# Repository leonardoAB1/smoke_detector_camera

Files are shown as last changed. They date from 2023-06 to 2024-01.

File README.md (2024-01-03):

# Smoke Detector Camera

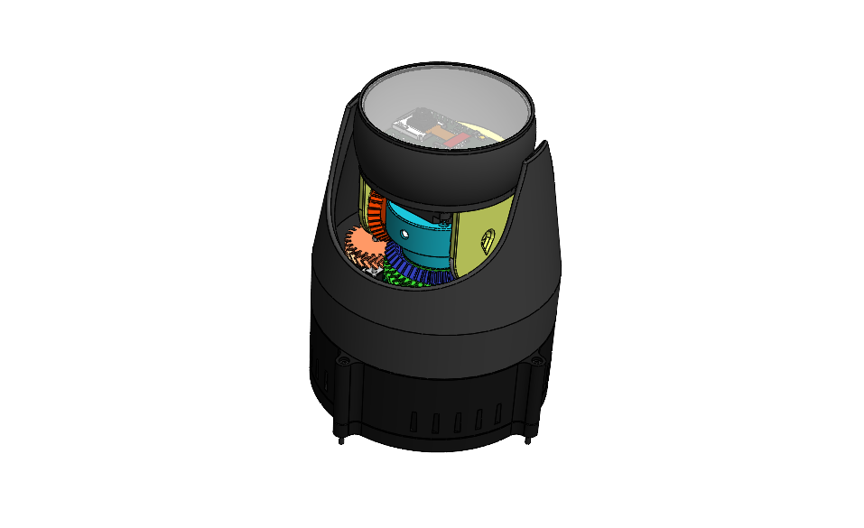
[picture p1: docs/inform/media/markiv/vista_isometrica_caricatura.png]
Vista Isometrica de la Version MK IV


"Smoke Detector Camera" is a project that aims to detect smokers and vaporizer users in a closed environment. The project combines the development of a local website using Django and web technologies such as HTML, CSS, and JavaScript, with the connection of an ESP32-CAM camera running FreeRTOS. Additionally, libraries like OpenCV and PyTorch will be used for image calculations and analysis.

The Django-based website will receive and display the data captured by the camera, as well as perform additional processing to successfully differentiate smokers from vaporizer users. Deep learning models and algorithms will be employed to detect and classify actions and gestures related to tobacco and vaporizer consumption.

Furthermore, there is a possibility of building a database to store captured images for long-term recording and analysis. The SQL database management system provided by Django will be utilized for this purpose.

In summary, "Smoke Detector Camera" is a project that combines web technologies, computer vision, and deep learning to detect and differentiate smokers from vaporizer users in a closed environment.

# IoT Project Directory Structure

This repository contains the directory structure for an IoT project. The structure is designed to organize the different components of the project and provide a logical arrangement for source code, documentation, configuration files, and more.

## Directory Structure

The project directory is structured as follows:

- **/docs**: Contains project documentation files, including system architecture, API documentation, and user manuals. The documentation is written in LaTeX.

- **/src**: Holds the source code files for different components of the IoT system.
  - **/device**: Contains device-specific code, firmware, or software that runs on the IoT devices/sensors.
  - **/gateway**: Includes code related to the gateway or edge computing component of the IoT project.
  - **/cloud**: Contains code related to the cloud or backend infrastructure, including data processing, storage, and API endpoints.

- **/config**: Contains configuration files for different components or modules within the project.

- **/tests**: Includes test files for unit tests, integration tests, or any other test-related files.

- **/data**: Contains data files required for the project, such as sample datasets.

- **/deploy**: Holds deployment-related files, such as deployment scripts or configuration files.

- **/scripts**: Contains utility scripts that assist in development, automation, or deployment tasks.

- **/logs**: Holds log files generated by the application or system.

- **/cad**: Contains CAD files related to the project, such as component designs, enclosures, schematics, and diagrams.

- **/electronics**: Holds electronics-related files, such as circuit diagrams, PCB layouts, datasheets, and schematics.

## Usage

To use this directory structure for your own IoT project, you can follow these steps:

1. Clone or download this repository to your local machine.

2. Customize the directories and subdirectories based on your project requirements.

3. Add your project-specific files and code to the corresponding directories.

4. Update the README.md file to provide an overview of your project and instructions for setup or usage.

## Contributing

If you have any suggestions or improvements for the directory structure or would like to contribute to this project, please feel free to submit a pull request.

## License

This project is licensed under the [MIT License](LICENSE).

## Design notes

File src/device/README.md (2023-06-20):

# Smoke Detector Camera - Servidor Móvil

## Descripción del proyecto

El proyecto Smoke Detector Camera utiliza la cámara ESP32-CAM para capturar video continuamente y enviarlo a un servidor para su procesamiento. El objetivo principal es detectar fumadores en las imágenes del video y tomar medidas en consecuencia.

El servidor móvil actúa como una interfaz de comunicación entre la cámara y el backend basado en Django. Recibe el video transmitido por la cámara y lo envía al servidor para su procesamiento. El servidor utiliza algoritmos de detección de fumadores para analizar las imágenes del video y generar resultados.

Este proyecto se basa en la plataforma ESP-IDF para el desarrollo del firmware de la cámara ESP32-CAM y en Django para el desarrollo del servidor.

## Características

- Captura y transmisión de video en tiempo real desde la cámara ESP32-CAM al servidor.
- Procesamiento de imágenes del video para detectar fumadores.
- Interfaz de comunicación entre la cámara y el servidor.
- Configuración sencilla y flexible a través de archivos de configuración.

## Requisitos previos

Antes de ejecutar el servidor móvil, asegúrate de tener los siguientes requisitos previos:

1. Cámara ESP32-CAM con firmware actualizado.
2. Servidor basado en Django correctamente configurado y en funcionamiento.
3. Conexión estable a internet.

# Web Server API Documentation

This document provides the documentation for the REST API of the web server implemented in the `web_server.c` file. The web server runs on an ESP32-CAM development board and provides various functionalities accessible through different URI endpoints.

## Base URL

The base URL for accessing the web server API is `http://localhost/` or `http://<ip_address>/` where `<ip_address>` is the IP address of the ESP32-CAM board.

## API Endpoints

The following table lists the available API endpoints along with their corresponding URIs, HTTP methods, and handlers:

| URI | Method | Handler | Description |
|---|---|---|---|
| `/image` | GET | `image_httpd_handler` | Get a single image |
| `/image64` | GET | `image_base64_httpd_handler` | Get a single image base64 encoded |
| `/status` | GET | `status_httpd_handler` | Get the camera status |
| `/admin` | POST | `admin_httpd_handler` | Admin functionality |
| `/motor_01/set` | POST | `handle_set_motor_angle` | Set the angle of motor 01 |
| `/motor_01/get` | GET | `handle_get_motor_angle` | Get the angle of motor 01 |
| `/motor_02/set` | POST | `handle_set_motor_angle` | Set the angle of motor 02 |
| `/motor_02/get` | GET | `handle_get_motor_angle` | Get the angle of motor 02 |
| `/ldr/set` | POST | `handle_set_ldr` | Set the state of the LDR |
| `/ldr/get` | GET | `handle_get_ldr` | Get the state of the LDR |
| `/led/set` | POST | `handle_set_led` | Set the state of the LED |
| `/led/get` | GET | `handle_get_led` | Get the state of the LED |
| `/smoke_sensor/set`  | POST | `handle_set_smoke_sensor` | Set the state of the smoke sensor (testing)  |
| `/smoke_sensor/get`  | GET | `handle_get_smoke_sensor` | Get the state of the smoke sensor |

## Request and Response Formats

### `/image` - Get a single image

**Request:**

- Method: GET

**Response:**

- Content Type: image/jpeg
- Body: Binary image data

### `/image64` - Get a single image base64 encoded

**Request:**

- Method: GET

**Response:**

- Content Type: image/jpeg
- Body: Base64-encoded image data

### `/status` - Get the camera status

**Request:**

- Method: GET

**Response:**

- Content Type: application/json
- Body: JSON object representing the status
  - Example response:
    ```json
    {
      "status": "online"
    }
    ```

### `/admin` - Admin functionality

**Request:**

- Method: POST
- Headers:
  - `Content-Length`: Length of the request body in bytes
- Body: JSON object containing admin-specific data
  - Example request body:
    ```json
    {
      "value": 42
    }
    ```

**Response:**

- Content Type: text/plain
- Body: Success message indicating the value was updated successfully

### `/motor_01/set - Set the angle of motor 01

**Request:**

- Method: POST
- Headers:
  - `Content-Length`: Length of the request body in bytes
- Body: JSON object containing the angle value
  - Example request body:
    ```json
    {
      "angle": 90
    }
    ```

**Response:**

- Content Type: text/plain
- Body: Success message indicating the angle was set successfully

### `/motor_01/get` - Get the angle of motor 01

**Request:**

- Method: GET

**Response:**

- Content Type: application/json
- Body: JSON object containing the current angle value
  - Example response:
    ```json
    {
      "angle": 90
    }
    ```

### `/motor_02/set` - Set the angle of motor 02

**Request:**

- Method: POST
- Headers:
  - `Content-Length`: Length of the request body in bytes
- Body: JSON object containing the angle value
  - Example request body:
    ```json
    {
      "angle": 180
    }
    ```

**Response:**

- Content Type: text/plain
- Body: Success message indicating the angle was set successfully

### `/motor_02/get` - Get the angle of motor 02

**Request:**

- Method: GET

**Response:**

- Content Type: application/json
- Body: JSON object containing the current angle value
  - Example response:
    ```json
    {
      "angle": 180
    }
    ```

### `/ldr/set` - Set the state of the LDR

**Request:**

- Method: POST
- Headers:
  - `Content-Length`: Length of the request body in bytes
- Body: JSON object containing the state value (`1` for high, `0` for low)
  - Example request body:
    ```json
    {
      "state": 1
    }
    ```

**Response:**

- Content Type: text/plain
- Body: Success message indicating the state was set successfully

### `/ldr/get` - Get the state of the LDR

**Request:**

- Method: GET

**Response:**

- Content Type: application/json
- Body: JSON object containing the current state value (`1` for high, `0` for low)
  - Example response:
    ```json
    {
      "state": 1
    }
    ```

### `/led/set` - Set the state of the LED

**Request:**

- Method: POST
- Headers:
  - `Content-Length`: Length of the request body in bytes
- Body: JSON object containing the state value (`1` for on, `0` for off)
  - Example request body:
    ```json
    {
      "state": 1
    }
    ```

**Response:**

- Content Type: text/plain
- Body: Success message indicating the state was set successfully

# Licencia

Este proyecto está licenciado bajo la [Licencia MIT](https://opensource.org/licenses/MIT).

# Contacto

Si tienes alguna pregunta, no dudes en contactarnos.

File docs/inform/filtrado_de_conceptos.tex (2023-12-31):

\needspace{3cm}
\subsection{Matriz de Selección}

En el proceso de diseño del hardware de la cámara inteligente, se llevará a cabo una comparación en el Cuadro~\ref{tab:matriz-conceptos} con un producto existente, en este caso, la cámara comercial Xiaomi Domo, que se muestra en la Figura~\ref{fig:XiamiDomo}.

\begin{table}[H]
\centering
\begin{tabularx}{\textwidth}{|X|c|c|c|c|c|c|c|}
\hline
\cellcolor{lightgray}\textbf{Conceptos} & \cellcolor{lightgray}\textbf{1} & \cellcolor{lightgray}\textbf{2} & \cellcolor{lightgray}\textbf{3} & \cellcolor{lightgray}\textbf{4} & \cellcolor{lightgray}\textbf{5} & \cellcolor{lightgray}\textbf{14} & \cellcolor{lightgray}\textbf{REF} \\
\hline
Integración de Componentes Electrónicos & + & 0 & + & + & - & +& 0\\
\hline
Facilidad de Mantenimiento & - & - & + & + & 0 & 0& 0 \\
\hline
Facilidad de Manufactura con Impresión 3D & + & + & + & + & - & +& 0 \\
\hline
Peso & 0 & - & 0 & - & 0 & -& 0 \\
\hline
Volumen & + & - & + & - & 0 & 0& 0 \\
\hline
Durabilidad & + & + & + & + & - & + & 0 \\
\hline
Costo de Producción & - & - & + & + & - & 0 & 0 \\
\hline
\cellcolor{lightgray} Suma +& \cellcolor{lightgray}4 & \cellcolor{lightgray}2 & \cellcolor{lightgray}6 & \cellcolor{lightgray}5 & \cellcolor{lightgray}0 & \cellcolor{lightgray}3 & \cellcolor{lightgray}0 \\
\hline
\cellcolor{lightgray} Suma 0\cellcolor{lightgray}& \cellcolor{lightgray}1 & \cellcolor{lightgray}1 & \cellcolor{lightgray}1 & \cellcolor{lightgray}0 & \cellcolor{lightgray}3 & \cellcolor{lightgray}3 & \cellcolor{lightgray}7 \\
\hline
\cellcolor{lightgray} Suma -& \cellcolor{lightgray}2 & \cellcolor{lightgray}4 & \cellcolor{lightgray}0 & \cellcolor{lightgray}2 & \cellcolor{lightgray}4 & \cellcolor{lightgray}1 & \cellcolor{lightgray}0 \\
\hline
Evaluación neta & 2 & -2 & 6 & 3 & -4 & 2 & 0 \\
\hline
Lugar & 3 & 5 & 1 & 2 & 6 & 3 & 4 \\
\hline
¿Continuar? & Combinar & No & Si & Combinar & No & No & No \\
\hline
\end{tabularx}
\caption{Matriz de Selección de Conceptos}
\label{tab:matriz-conceptos}
\end{table}

Al observar el Cuadro~\ref{tab:matriz-conceptos}, se evidencia que la unión de los conceptos 1 y 4 no presenta un desempeño superior al del concepto 3. Por lo tanto, se opta por emplear los conceptos en el primer y segundo puesto.

\needspace{3cm}
\subsection{Evaluación de Conceptos}

\begin{table}[H]
\centering
\small
\begin{tabularx}{\textwidth}{|l|X|X|X|}
\hline
 & Concepto 3  & Concepto 4 & Referencia\\
\hline

    \begin{tabular}{@{}p{4cm}|p{1cm}@{}}
    Criterios & Peso \\
    \end{tabular} 
    &
    \begin{tabular}{@{}p{0.9cm}|p{2.4cm}@{}}
    Calif. & Ev.Pond. \\
    \end{tabular}
    & 
    \begin{tabular}{@{}p{0.9cm}|p{2.4cm}@{}}
    Calif. & Ev.Pond. \\
    \end{tabular}
    & 
    \begin{tabular}{@{}p{0.9cm}|p{2.4cm}@{}}
    Calif. & Ev.Pond. \\
    \end{tabular}
    \\
    \hline
    %Fila 1
    \begin{tabular}{@{}p{4cm}|p{1cm}@{}}
    Integración Electronica & 15\% \\
    \end{tabular} 
    &
    \begin{tabular}{@{}p{0.9cm}|p{2.4cm}@{}}
    5 &  0.75 \\
    \end{tabular}
    & 
    \begin{tabular}{@{}p{0.9cm}|p{2.4cm}@{}}
    4 & 0.6  \\
    \end{tabular}
    & 
    \begin{tabular}{@{}p{0.9cm}|p{2.4cm}@{}}
    5 &  0.75 \\
    \end{tabular}
    \\
    \hline
    %Fila 2
    \begin{tabular}{@{}p{4cm}|p{1cm}@{}}
    Facil. Mantenimiento & 15\% \\
    \end{tabular} 
    &
    \begin{tabular}{@{}p{0.9cm}|p{2.4cm}@{}}
     4 &  0.6 \\
    \end{tabular}
    & 
    \begin{tabular}{@{}p{0.9cm}|p{2.4cm}@{}}
     4 &  0.6 \\
    \end{tabular}
    & 
    \begin{tabular}{@{}p{0.9cm}|p{2.4cm}@{}}
    3 &  0.45 \\
    \end{tabular}
    \\
    \hline
    %Fila 3
    \begin{tabular}{@{}p{4cm}|p{1cm}@{}}
    Facilidad Manufactura & 15\% \\
    \end{tabular} 
    &
    \begin{tabular}{@{}p{0.9cm}|p{2.4cm}@{}}
    5 &  0.75 \\
    \end{tabular}
    & 
    \begin{tabular}{@{}p{0.9cm}|p{2.4cm}@{}}
    4 &  0.6 \\
    \end{tabular}
    & 
    \begin{tabular}{@{}p{0.9cm}|p{2.4cm}@{}}
    3 & 0.45 \\
    \end{tabular}
    \\
    \hline
    %Fila 4
    \begin{tabular}{@{}p{4cm}|p{1cm}@{}}
    Peso & 10\% \\
    \end{tabular} 
    &
    \begin{tabular}{@{}p{0.9cm}|p{2.4cm}@{}}
    3 &  0.3 \\
    \end{tabular}
    & 
    \begin{tabular}{@{}p{0.9cm}|p{2.4cm}@{}}
    5&  0.5 \\
    \end{tabular}
    & 
    \begin{tabular}{@{}p{0.9cm}|p{2.4cm}@{}}
    5& 0.5 \\
    \end{tabular}
    \\
    \hline
    %Fila 5
     \begin{tabular}{@{}p{4cm}|p{1cm}@{}}
     Volumen & 10\% \\
    \end{tabular} 
    &
    \begin{tabular}{@{}p{0.9cm}|p{2.4cm}@{}}
    3 & 0.3  \\
    \end{tabular}
    & 
    \begin{tabular}{@{}p{0.9cm}|p{2.4cm}@{}}
    4 & 0.4 \\
    \end{tabular}
    & 
    \begin{tabular}{@{}p{0.9cm}|p{2.4cm}@{}}
     5& 0.5 \\
    \end{tabular}
    \\
    \hline
    %Fila 6
    \begin{tabular}{@{}p{4cm}|p{1cm}@{}}
    Durabilidad & 15\% \\
    \end{tabular} 
    &
    \begin{tabular}{@{}p{0.9cm}|p{2.4cm}@{}}
    4&  0.6 \\
    \end{tabular}
    & 
    \begin{tabular}{@{}p{0.9cm}|p{2.4cm}@{}}
     5 & 0.75  \\
    \end{tabular}
    & 
    \begin{tabular}{@{}p{0.9cm}|p{2.4cm}@{}}
     3 & 0.45 \\
    \end{tabular}
    \\
    \hline
    %Fila 7
    \begin{tabular}{@{}p{4cm}|p{1cm}@{}}
    Costo de Producción & 20\% \\
    \end{tabular} 
    &
    \begin{tabular}{@{}p{0.9cm}|p{2.4cm}@{}}
     4 &  0.8 \\
    \end{tabular}
    & 
    \begin{tabular}{@{}p{0.9cm}|p{2.4cm}@{}}
     3 &  0.6 \\
    \end{tabular}
    & 
    \begin{tabular}{@{}p{0.9cm}|p{2.4cm}@{}}
     4&  0.8\\
    \end{tabular}
    \\
    \hline
    %Fila 8
    \begin{tabular}{@{}p{4cm}|p{1cm}@{}}
    & Total \\
    \end{tabular} 
    &
    \begin{tabular}{@{}p{0.9cm}|p{2.4cm}@{}}
     &   4.1\\
    \end{tabular}
    & 
    \begin{tabular}{@{}p{0.9cm}|p{2.4cm}@{}}
     &   4.05\\
    \end{tabular}
    & 
    \begin{tabular}{@{}p{0.9cm}|p{2.4cm}@{}}
     &  3.9\\
    \end{tabular}
    \\
    \hline
    %Fila 9
    \begin{tabular}{@{}p{4cm}|p{1cm}@{}}
    & Lugar \\
    \end{tabular} 
    &
    \begin{tabular}{@{}p{0.9cm}|p{2.4cm}@{}}
    &  1 \\
    \end{tabular}
    & 
    \begin{tabular}{@{}p{0.9cm}|p{2.4cm}@{}}
     & 2 \\
    \end{tabular}
    & 
    \begin{tabular}{@{}p{0.9cm}|p{2.4cm}@{}}
     & 3 \\
    \end{tabular}
    \\
    \hline
    %Fila 10
    \begin{tabular}{@{}p{1cm} p{2.5cm}@{}}
    & ¿Continuar? \\
    \end{tabular} 
    &
    Desarrollar
    & 
    No
    & 
    No
    \\
    \hline
    
\end{tabularx}
\caption{Matriz de Evaluación de Conceptos}
\label{tab:eval_conceptos}
\end{table}

Tras un análisis riguroso del Cuadro~\ref{tab:eval_conceptos}, queda claro que el Concepto 3 se erige como la elección más sólida para avanzar en el proceso de desarrollo. Con una puntuación total de 4.1, este concepto ha superado tanto al Concepto 4 como a la referencia en todos los aspectos clave. La asignación de pesos a los criterios ha demostrado ser fundamental, y la fortaleza de Concepto 3 en términos de integración electrónica, facilidad de manufactura y costo de producción ha destacado de manera significativa. En contraste, el Concepto 4 ha obtenido una puntuación ligeramente inferior (4.05) y no logra cumplir con las expectativas establecidas. Estos resultados, respaldados por un análisis cuantitativo, respaldan la recomendación de avanzar con el desarrollo del Concepto 3, mientras que sugieren una revisión más profunda o una reconsideración del "Concepto 4" antes de continuar con su implementación.

\needspace{3cm}
\subsection{Combinación y Mejora de Conceptos}
Analizando las fortalezas del Concepto 3 con respecto al Concepto 4 
 en el Cuadro~\ref{tab:eval_conceptos} Se puede notar que el este primero tiene desventajas en términos de peso y volumen. Esto se debe que cuenta con ventiladores directamente encima del circuito electrónico imponiendo una restricción de espacio para e diseño del hardware. A su vez, al estar parte del circuito en movimiento sobre el mecanismo propuesto se debe considerar la posición del ventilador y sus cables con respecto a dicho mecanismo; Podría ser interesante explorar el Concepto 3 con otra elección conceptual de gestión termica.

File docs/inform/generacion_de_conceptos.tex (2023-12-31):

\needspace{3cm}
\subsection{Aclaración del Problema}
Desde el punto de vista de diseño mecánico del producto, el objetivo es diseñar un sistema embebido que debe ocupar las mínimas dimensiones. Estas dimensiones están limitadas por tres factores:

\begin{itemize}
    \item El tamaño y forma de los dispositivos electrónicos contenidos.
    \item El espacio que ocupan los sistemas auxiliare, en este caso baterías y refrigeración.
    \item El espacio que ocupan los actuadores a fin de garantizar dos grados de libertad.
\end{itemize}

Se conocen las especificaciones técnicas del mínimo de sensores a utilizar y el tamaño del microcontrolador seleccionado por el equipo de diseño electrónico, el resto de elementos quedan a criterio del equipo de diseño mecánico.

Más aun, se debe diseñar el sistema para manufactura en masa en impresoras FDM (\textit{Filament Deposition Modeling}).

\subsubsection{Especificaciones de Componentes Electrónicos}
\begin{itemize}
    \needspace{3cm}
    \item \textbf{ESP32 CAM12}
    \begin{itemize}
        \item Dimensiones: 40.5mm x 27mm x 4.5mm
        \item Voltaje de alimentación: 5V
        \item Consumo de energía: Menos de 800mW en funcionamiento, tan bajo como 6mA en modo de suspensión profunda
        \item Temperatura de funcionamiento: -20 ℃ ~ 85 ℃
    \end{itemize}
    
    \needspace{3cm}
    \item \textbf{HC-SR501345}
    \begin{itemize}
        \item Dimensiones: 32mm x 24mm
        \item Voltaje de alimentación: 4.5V - 20V (5V recomendado)
        \item Consumo de energía: 65mA
        \item Temperatura de funcionamiento: -20 °C ~ +70 °C
    \end{itemize}

    \needspace{5cm}
    \item \textbf{MQ-135678}
    \begin{itemize}
        \item Dimensiones: 18mm de diámetro, 17mm de alto sin contar los pines
        \item Voltaje de alimentación: 2.5V ~ 5.0V
        \item Consumo de energía: No especificado
        \item Temperatura de funcionamiento: No especificado
    \end{itemize}
\end{itemize}

\subsubsection{Descomposición del Problema}
Tomando en cuenta las limitaciones del producto se puede descomponer el sistema en cuatro subsistemas principales: Procesamiento de las señales de los sensores, administración de energía, sistema de movimiento y gestión termica o direccionamiento de aire. La Figura \ref{fig:analisis_funcional} describe por medio de un diagrama de bloques la interacción entre estos subsistemas: La energía eléctrica entra al bloque de administración de energía, dentro del mismo la energía se puede almacenar en baterías, alternar su naturaleza o nivel. Este bloque se conecta a todos los subsistemas: Procesamiento, movimiento y direccionamiento de aire. A su vez, el bloque de procesamiento puede o no controlar los sistemas de direccionamiento de aire y de movimiento.

\begin{figure}[H]
\centering
\begin{adjustbox}{width=\linewidth}
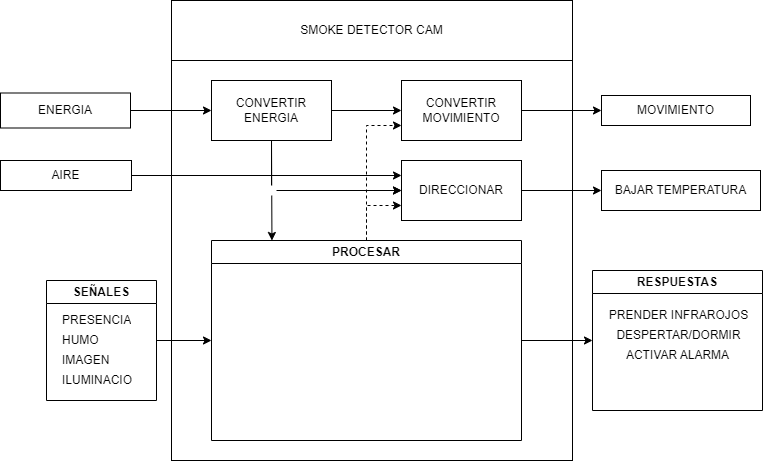
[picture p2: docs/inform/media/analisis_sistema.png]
  
\end{adjustbox}
\caption{\label{fig:analisis_funcional}Análisis Funcional del Sistema.}
\end{figure}

\subsubsection{Subproblemas Críticos}
\begin{enumerate}[label=\alph*)]
    \item Administración de Energía
        \needspace{3cm}
        \begin{enumerate}[label=\Roman*)]
            \item \textbf{Selección de cables y conectores adecuados:} Elegir cables y conectores de alta calidad y con capacidades de corriente adecuadas para minimizar la pérdida de energía y garantizar una transmisión de energía eficiente.
    
            \needspace{3cm}
            \item \textbf{Enrutamiento de cables:} Planificar cuidadosamente la disposición de los cables dentro del dispositivo para evitar cruces, pliegues o torsiones excesivas que puedan causar pérdida de energía o dañar los cables con el tiempo.
    
            \needspace{3cm}
            \item \textbf{Protección contra cortocircuitos:} Implementar mecanismos de protección, como fusibles o disyuntores, para prevenir cortocircuitos que podrían dañar los cables y afectar la administración de energía.
    
            \needspace{3cm}
            \item \textbf{Acceso y mantenimiento:} Diseñar el sistema mecánico de manera que sea fácil acceder a los cables y conectores para el mantenimiento y la sustitución, si es necesario, sin tener que desmontar todo el dispositivo.
    
            \item \textbf{Selección de batería:} La elección de la batería se realiza cuidadosamente, considerando los requisitos de energía específicos de los actuadores del dispositivo, como motores, sensores y otros componentes, y asegurando que la batería seleccionada tenga la capacidad adecuada para suministrar la energía requerida de manera constante y confiable. Además, se evalúa minuciosamente el tamaño y la forma de la batería para garantizar su integración eficiente en el diseño mecánico del dispositivo, optimizando así el espacio disponible y manteniendo un equilibrio adecuado entre la capacidad de la batería y las limitaciones de tamaño del dispositivo.
        \end{enumerate}
        
    \item Sistema de Movimiento
    \begin{enumerate}[label=\Roman*)]
        \item \textbf{Requisitos de movimiento:} Define claramente los requisitos de movimiento del dispositivo, incluyendo los rangos de movimiento, las velocidades y las aceleraciones necesarias para cumplir con su función prevista.
        
        \item \textbf{Selección de actuadores:} Elije los actuadores adecuados para controlar el movimiento en los dos grados de libertad. Considera motores eléctricos, motores paso a paso, actuadores lineales o cualquier otro tipo de actuador que se adapte a tus necesidades.
        
        \item \textbf{Mecanismos de control de movimiento:} Analizar la incorporación de sistemas de guía o mecanismos para garantizar un movimiento suave y preciso en el rango requerido. 
        
        \item \textbf{Costos:} Gestiona el presupuesto disponible para el proyecto y selecciona componentes y materiales que se ajusten a él sin comprometer la calidad y el rendimiento del dispositivo.
        
        \item \textbf{Montaje:} Planificar el montaje de los actuadores tomando en cuenta el proceso de fabricación y herramientas de montaje.
    \end{enumerate}

\item Gestión Térmica
    \begin{enumerate}[label=\Roman*)]
        \needspace{3cm}
        \item \textbf{Selección de ventiladores o actuadores:} Seleccionar los ventiladores o actuadores adecuados basándose en los requisitos de flujo de aire del dispositivo y las características de capacidad, eficiencia y durabilidad.

        \needspace{3cm}
        \item \textbf{Distribución del flujo de aire:} Diseñar y asegurarse de que los conductos de aire estén configurados de manera que el flujo de aire se distribuya de manera uniforme en todo el dispositivo.

        \needspace{3cm}
        \item \textbf{Espacio y restricciones de tamaño:} Diseñar el sistema de direccionamiento de aire teniendo en cuenta las limitaciones de espacio y tamaño para asegurarse de que se ajuste correctamente en el dispositivo embebido.

        \needspace{3cm}
        \item \textbf{Gestión de costos:} Gestionar el presupuesto del proyecto y seleccionar componentes y materiales que se ajusten a él sin comprometer la calidad y el rendimiento del sistema de gestión térmica.

        \needspace{3cm}
        \item \textbf{Planificación de fabricación y montaje:} Planificar cómo se fabricarán los componentes del sistema de dirección de aire y cómo se ensamblarán de manera eficiente, eligiendo procesos de fabricación adecuados y herramientas de montaje.
    \end{enumerate}
\end{enumerate}

\needspace{3cm}
\subsection{Búsqueda Externa}
\subsubsection{Análisis de Literatura}
Se dividió el análisis de literatura en base a los tres problemas principales que se desea solucionar:

    \begin{enumerate}[label=\alph*)]
    \item \textbf{Administración de Energía} \\
    Esta sección desarrolla dos aspectos fundamentales del diseño de productos electrónicos: La gestión de cables y la selección de baterías.  La gestión de cables cumple dos funciones esenciales: Garantizar la seguridad de los cables en una aplicación y dirigirlos a través de puntos de acceso. 

    \begin{enumerate}[label=\Roman*)]
    \item \textbf{Selección de Baterias} \\
    \begin{itemize}
    
    \needspace{8cm}
    \item \textbf{Baterías No Recargables}
    
        \begin{table}[H]
        \centering
        \begin{tabularx}{\textwidth}{|c|X|X|X|}
        \hline
        \textbf{Tipo} & \textbf{Ventajas} & \textbf{Desventajas} & \textbf{Usos} \\
        \hline
        Baterías Alcalinas & Tamaño pequeño, Eficientes, Baja fuga & Costo elevado & Linternas, mandos a distancia, pequeños electrodomésticos \\
        \hline
        Baterías de Botón & Livianas, alta densidad, bajo costo, alto voltaje nominal & Requiere un soporte, baja capacidad de corriente & Relojes, relojes de pared, productos electrónicos en miniatura \\
        \hline
        \end{tabularx}
        \caption{Análisis de Baterías No Recargables}
        \label{tab:baterias_no_recargables}
        \end{table}

    \needspace{4cm}
    \item \textbf{Baterías Secundarias Comunes}
    
        \begin{table}[H]
        \centering
        \begin{tabularx}{\textwidth}{|c|X|X|X|X|}
        \hline
        \textbf{Tipo} & \textbf{Plomo-Ácido} & \textbf{NiCd} & \textbf{NiMH} & \textbf{Li-Ion*} \\
        \hline
        Voltaje de Celda & 2V & 1.2V & 1.2V & 3.2-3.6V \\
        \hline
        Voltaje de Corte de Descarga & 1.75V & 1.00V & 1.00V & 2.50V \\
        \hline
        Corriente de Descarga & 5C & 20C & 5C & 2C o >30C \\
        \hline
        Vida Útil de Ciclo & 200-300 & 1000 & 300-500 & 500-1000 \\
        \hline
        Auto-Descarga / mes & 5\% & 20\% & 30\% & <5\% \\
        \hline
        Temperatura de Carga & -20 a 50°C & 0 a 45°C & 0 a 45°C & 0 a 45°C \\
        \hline
        Temperatura de Descarga & -20 a 50°C & -20 a 65°C & -20 a 65°C & -20 a 60°C \\
        \hline
        Requisito de Mantenimiento & 3-6 meses & Descarga completa cada 90 días en uso completo & Descarga completa cada 90 días en uso completo & No requerido \\
        \hline
        Costo & Bajo & Moderado & Moderado & Alto \\
        \hline
        \end{tabularx}
        \caption{Análisis de Baterías Recargables}
        \label{tab:baterias_recargables}
        \end{table}
        
        La Tabla \ref{tab:baterias_recargables} ofrece una comparativa de diferentes tipos de baterías recargables. Las "Plomo-Ácido" son económicas pero requieren mantenimiento regular. Las "NiCd" y "NiMH" son duraderas pero necesitan descargas periódicas. Las "Li-Ion*" son versátiles y sin mantenimiento, pero tienen un costo más elevado; Para uso general las baterías de Li-ion son las más adecuadas debido a la falta de mantenimiento, una larga vida útil de ciclo y una baja auto-descarga. Esto es por qué son populares en muchos aparatos como laptops y teléfonos móviles. Sin embargo, una desventaja es el costo (\cite{tan2020guide}).
        
    \end{itemize}

    \item \textbf{Manejo de Cables} 
    
    Para optimizar el tiempo de operación de su aplicación y evitar costosas reparaciones, es fundamental proteger los cables contra daños directos. Para esta tarea, se puede contar con soluciones como conducciones, envolturas para cables, casquillos de alivio de tensión y cajas de conexiones. Sin embargo, cuando se trata de orientar y administrar múltiples cables de manera eficiente, se consideran otras alternativas, como ser sujeta-cables, clips para cables, envolturas de cable y pasa-cables(\cite{essentraCableManagement}). Estos elementos permiten dirigir estratégicamente los cables.
    Cada una de las soluciones presentadas a continuación es esencial para resolver ciertos problemas cuando se trata de la organización de cables y mejorar la gestión de cables:

    \begin{figure}[H]
    \centering
    \begin{adjustbox}{width=\linewidth/2}
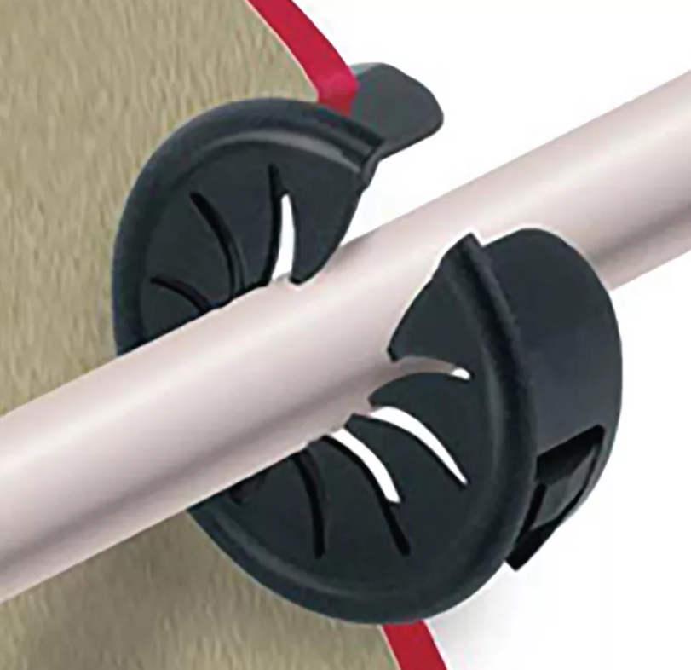
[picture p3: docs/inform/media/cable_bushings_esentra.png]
      
    \end{adjustbox}
    \caption{\label{fig:cable_bushings}Arandela para cables.}
    Fuente: \textcite{essentraCableManagement}.
    \end{figure}
    
    \begin{itemize}
    \item \textbf{Arandelas para cables:} Permiten que los cables pasen de manera segura a través de una barrera conductora conectada a tierra, como chapa metálica, un transformador o un interruptor.
    \item \textbf{Clips para cables:} Aseguran los cables en una superficie como se ve en la Figura \ref{fig:cable_bushings}.
    \item \textbf{Abrazaderas para cables:} Proporcionan soporte mientras definen una ruta para los cables a lo largo de una pared o dentro de una aplicación.
    \item \textbf{Correas para cables:} Mantienen un pequeño grupo de cables juntos para mantenerlos organizados.
    \item \textbf{Monturas para correas para cables:} Elemento de fijación para correas para cables, aplicado a superficies.
    \item \textbf{Envolturas y fundas para cables:} Organizan los cables en un solo paquete.
    \item \textbf{Glandes para cables:} Evitan daños y fallos en los cables y se utilizan para pasar cables a una carcasa o dispositivo de control. Por lo general, se utilizan en entornos industriales para controlar la curva o evitar que un cable se salga de un sistema.
    \item \textbf{Tubos termorretráctiles:} Aíslan los cables, proporcionando resistencia a la abrasión y protección ambiental. Disponibles en diferentes colores para permitir la codificación por colores.
    \item \textbf{Correas de torsión:} Ideales para circuitos y placas eléctricas. Mantienen los cables en su lugar, alejados de los paneles.
    \end{itemize}
    
    La gestión de cables es crucial para mantener la organización y la seguridad en entornos donde se utilizan cables y alambres. Cada una de estas soluciones desempeña un papel importante en abordar problemas específicos relacionados con la gestión de cables, desde la protección contra daños hasta la organización efectiva. Estos productos y materiales son esenciales para garantizar que los cables funcionen de manera confiable y se mantengan ordenados en diversas aplicaciones, desde entornos industriales hasta aplicaciones domésticas.

    \end{enumerate}

    \item \textbf{Sistema de Movimiento} \\
    Una revisión inicial de literatura permite observar que existen dos soluciones que se pueden dar al problema de movimiento panorámico e inclinación requerido por el sistema: Utilizar directamente dos actuadores en serie que con control de lazo cerrado de posición similar al de \textcite{Yosafat2017} o utilizar algún mecanismo diseñado para este propósito como el que expone \textcite{diff_pan_tilt_youtube}. A estos últimos se los denomina como Generadores de Movimiento Panorámico y de Inclinación, \textit{PTMG} por sus siglas en ingles. La primera solución implicando un incremento de tamaño, precisión y velocidades limitadas mientras que la segunda soluciona todos los problemas de la primera, pero implica una mayor complejidad de diseño (\cite{Alizadeh2010}) y en muchos casos de manufactura.

    Siendo así, inicialmente y en base a la información proporcionada por \textcite{motorSelection} se desarrolló la comparación de motores del Cuadro \ref{tab:motor-comparison}.
    
    \begin{table}[H]
        \centering
        \begin{tabularx}{\textwidth}{|c|c|X|X|X|}
            \hline
            \textbf{Tipo de Motor} & \textbf{Ruido} & \textbf{Mantenimiento} & \textbf{Ventajas} & \textbf{Limitaciones} \\
            \hline
            Motor DC & Alto & Constante & Adecuados para soluciones de bajo costo. Generan ruido eléctrico. Velocidad limitada debido al calentamiento de las escobillas. & Requieren controladores adicionales. \\
            \hline
            Motor Brushless & Bajo & Medio & Eficientes con bajo ruido eléctrico. Alta durabilidad. & Costo inicial más alto. \\
            \hline
            Motor a Paso & Medio & Medio & Posicionamiento preciso, control de velocidad y alto par a bajas velocidades. Alto par de retención. & Requieren un controlador de pasos. \\
            \hline
            Servomotor & Bajo & Poco & Alto par a altas velocidades, variedad en tamaños y opciones rentables. & Rango de movimiento limitado, posibles sacudidas. \\
            \hline
        \end{tabularx}
        \caption{Comparación de Motores}
        \label{tab:motor-comparison}
    \end{table}

    Si se prioriza una operación silenciosa y eficiente, la mejor opción son los motores de corriente continua sin escobillas. Para realizar un posicionamiento preciso y mantener un control de velocidad, los motores paso a paso destacan gracias a su alto conteo de polos. Cuando se requieren capacidades de alta velocidad y alto par, los motores servo se convierten en la elección ideal, especialmente cuando se superan las 2000 rpm. En el caso de opciones económicas, se puede considerar los servos de tamaño pequeño. No obstante, si la búsqueda se enfoca en una solución rentable con niveles de ruido aceptables, los motores de corriente continua tradicionales también pueden ser apropiados. Es importante tener en cuenta que cada tipo de motor presenta sus propias limitaciones, por lo tanto, la elección debe ajustarse a los requisitos y limitaciones específicos del proyecto en cuestión.

    Por otro lado, se identificaron los PTMGs descritos a continuación; Notese que los primeros cuatro hacen uso de sistemas de engranes planetarios. Un sistema de engranajes planetarios está compuesto por un sol, dos planetas, una corona y un portaplanetas. Al activar los engranajes del sol y la corona, se logra el movimiento panorámico directamente a partir de la rotación del portaplanetas. Sin embargo, se necesita un mecanismo intermedio para transferir la rotación del planeta alrededor de su propio eje vertical al eje de inclinación del eje horizontal.
    
    \needspace{4cm}
    \begin{enumerate}[label=\Roman*)]
    \item \textbf{\textit{Bevel-gear train}:} Del mismo modo, los engranajes cónicos pueden transferir la rotación entre dos ejes que se cruzan. En consecuencia, se puede emplear un par de engranajes cónicos de manera simple para llevar a cabo la transmisión de la rotación desde el planeta hasta el eje de inclinación.

    \begin{figure}[H]
    \centering
    \begin{adjustbox}{width=\linewidth/2}
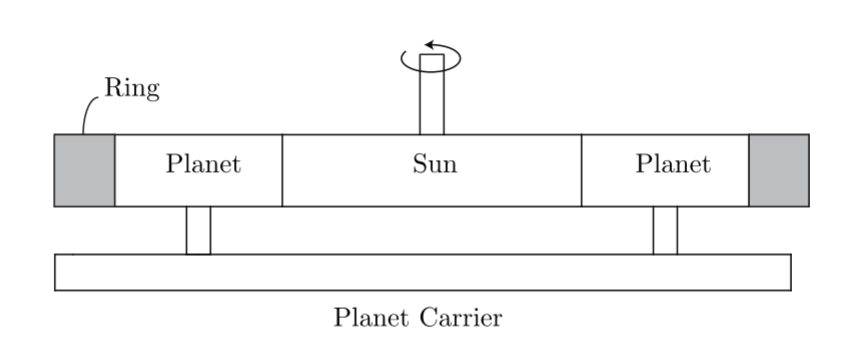
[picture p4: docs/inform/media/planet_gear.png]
      
    \end{adjustbox}
    \caption{\label{fig:planet_gear_mechanism}Mecanismo de tren de engranes planetarios.}
    Fuente: \textcite{Yosafat2017}
    \end{figure}
    
    \item \textbf{\textit{Homokinetic joints}:} Se trata de un tipo de conexión cinemática entre dos ejes que se cruzan se conoce como una junta homocinética o junta de velocidad constante (CV). Esto permite la transferencia de velocidad angular, par y potencia con una relación de 1:1. Estos acoplamientos se emplean para convertir el movimiento de rotación del planeta en movimiento de inclinación; Puede tratarse de, por ejemplo, por dos uniones universales o una union Rzeppa.
    
    \item \textbf{\textit{Five-bar linkage}:} Tal como se describe en el nombre, se trata de un mecanismo de cinco barras que produce el movimiento de inclinación por medio del movimiento del planeta.
    
    \item \textbf{\textit{Spherical linkage}:} Este mecanismo se caracteriza por diseñar sus ejes de entrada y salida de manera ortogonal, buscando lograr una relación de velocidad cercana a 1:1.
    
    \item \textbf{\textit{Differential gear train}:} Este PTMG, cuyo diagrama esquemático está la Figura \ref{fig:diff_mechanism}, emplea un tipo distinto de mecanismo de engranaje planetario en comparación con el que se describió inicialmente. El tren de engranajes diferencial es impulsado por dos motores idénticos A y B. El engranaje solar inferior está montado en un eje hueco y es impulsado por el motor A, mientras que el eje del engranaje solar superior, accionado por el motor B, pasa a través del eje hueco; esta disposición permite al diseñador colocar ambos motores en el marco de la base, en la parte inferior. La rotación del marco móvil alrededor del eje vertical produce el movimiento de panorámica, mientras que la rotación de los planetas alrededor de sus ejes proporciona el movimiento de inclinación.

    \begin{figure}[H]
    \centering
    \begin{adjustbox}{width=\linewidth/2}
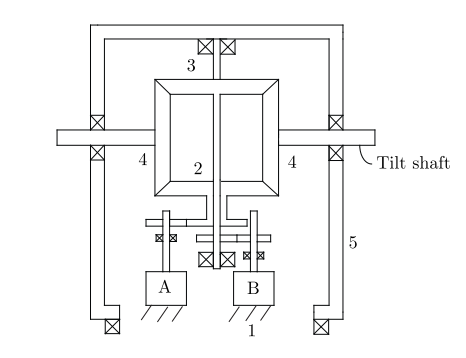
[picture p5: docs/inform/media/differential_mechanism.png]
      
    \end{adjustbox}
    \caption{\label{fig:diff_mechanism}Mecanismo de tren de engranes diferencial.}
    Fuente: \textcite{Yosafat2017}
    \end{figure}
    
    \item \textbf{\textit{Hervé's pan-tilt linkage}:} Hervé (2006) citado en \textcite{Yosafat2017} sintetizó varios PTMGs paralelos de dos miembros utilizando la teoría de grupos. Dado que los mecanismos propuestos en (Hervé, 2006) no están excesivamente restringidos, pueden tolerar errores en la fabricación y el ensamblaje. Además, las actuaciones de panorámica e inclinación están desacopladas, es decir, los ejes de panorámica e inclinación pueden ser accionados de manera independiente.
    \end{enumerate}
    
    \item \textbf{Gestión Térmica} \\
    Las tecnologías de gestión térmica se clasifican en sistemas de enfriamiento con contacto directo o indirecto con el fluido de enfriamiento, según si el fluido de enfriamiento entra o no en contacto directo con los componentes que se están enfriando. Dentro de la ventilación directa se considerara solamente la ventilación por aire debido a su bajo costo y popular uso en aparatos de consumo (\cite{zhang2021review}).

    \needspace{3cm}
    \begin{enumerate}[label=\Roman*)]
    \item \textbf{\textit{Directa: Ventilación de Aire de adelante hacia atrás:}} Enfoque de diseño y gestión térmica utilizado en sistemas electrónicos y equipos para disipar el calor generado por los componentes internos de manera eficiente (\cite{Group_2017}). En este enfoque, el flujo de aire fresco entra en el sistema desde el frente (o la parte delantera) del equipo y fluye hacia la parte trasera, pasando a través de los componentes electrónicos y llevando consigo el calor generado. Luego, el aire caliente se expulsa hacia afuera desde la parte trasera del equipo.

    Este método se utiliza para evitar que el aire caliente se mezcle con el aire fresco en el interior del sistema, lo que podría provocar un aumento de la temperatura y, en última instancia, el sobrecalentamiento de los componentes electrónicos. Al mantener un flujo de aire ordenado y unidireccional de frente a atrás, se puede mantener una temperatura adecuada dentro del equipo, lo que es fundamental para garantizar el rendimiento y la fiabilidad de los dispositivos electrónicos, como servidores, sistemas de almacenamiento, enrutadores y conmutadores, entre otros.

        \needspace{3cm}
        \begin{enumerate}[label=\alph*)]
        \item \textbf{Ventiladores en la Parte Trasera:}
        \begin{itemize}
            \item Los ventiladores se colocan directamente detrás del conjunto de placas electrónicas para extraer el calor.
            \item Aunque es eficaz, puede presentar desafíos en cuanto a la filtración del aire.
            \item Adecuado para muchas aplicaciones, pero puede no ser óptimo para procesadores de alta potencia y necesidades de entrada/salida trasera.
        \end{itemize}
    
        \item \textbf{Montaje Horizontal de Placas Electrónicas:}
        \begin{itemize}
            \item Las placas electrónicas se montan horizontalmente con una entrada de aire en la parte frontal izquierda y una salida en la parte trasera izquierda.
            \item Opción que ahorra espacio, especialmente en configuraciones con pocas ranuras.
            \item Menos eficiente en la refrigeración debido a áreas limitadas de entrada y salida (por ejemplo, un chasis de 4U puede refrigerar aproximadamente 90 vatios por ranura).
        \end{itemize}
    
        \item \textbf{Montaje Vertical de Placas Electrónicas:}
        \begin{itemize}
            \item Las placas electrónicas se montan verticalmente con una amplia entrada de aire en la parte frontal.
            \item Los ventiladores axiales tubulares en la parte trasera extraen el aire a lo largo de toda la entrada.
            \item Común en sistemas integrados, pero el flujo de aire puede enfrentar dos curvas de 90 grados, lo que se puede mejorar con deflectores de aire.
        \end{itemize}
    
        \item \textbf{Ventiladores Directamente Encima de las Placas Electrónicas:}
        \begin{itemize}
            \item Ventiladores potentes se ubican justo encima de las placas electrónicas.
            \item Estos ventiladores extraen aire hacia arriba y lo expulsan por la parte trasera, reduciendo la resistencia del flujo de aire.
            \item Minimiza el retroceso de aire y la contrapresión, mejorando el rendimiento de refrigeración en general.
        \end{itemize}
        \end{enumerate}

    \item \textbf{\textit{Indirecta}}

        La refrigeración por contacto indirecto implica que el medio de enfriamiento se encarga de disipar el calor junto con la estructura del disipador de calor externo. Es importante destacar que la brecha de aire entre el dispositivo electrónico y las superficies del disipador de calor, tiene un impacto significativo en el proceso de eliminación del calor.
     
        \begin{enumerate}[label=\alph*)]
            \needspace{5cm}
            \item \textbf{\textit{Canales de Refrigeración}:} 
                
            \textcite{Arrivabeni2021} presentó una metodología para optimizar el diseño de los canales de refrigeración conformados por moldes mediante una combinación de CAD, \textit{Computational Fluid Dynamics} (CFD) e impresión 3D, lo que permite la producción de piezas o sistemas que están profundamente entrelazados con la producción.
            De manera similar este trabajo busca utilizar estas capacidades del proceso para aumentar la capacidad de refrigeración, pero en este caso del sistema embebido, por medio de las capacidades de este tipo de manufactura para producir geometría compleja.
            Como describe \textcite{Shinde2017} los canales de enfriamiento estándar se crean mediante maquinaria en líneas rectas como se aprecia en la Figura \ref{fig:cooling_channels}. Esta técnica produce resultados irregulares debido a que el método convencional no logra proporcionar un enfriamiento uniforme en toda la cavidad del interior del contenedor.
        
            \begin{figure}[H]
            \centering
            \begin{adjustbox}{width=\linewidth/2}
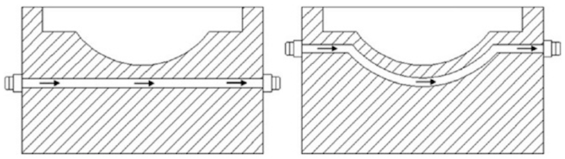
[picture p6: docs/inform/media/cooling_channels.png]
              
            \end{adjustbox}
            \caption{\label{fig:cooling_channels}Canales de enfriamiento convencionales y conformes.}
            Fuente: \textcite{Shinde2017}
            \end{figure}
        
            \item \textbf{\textit{Tubo de Calor}:} Los tubos de calor (\cite{richard1944gaugler}), son un eficaz dispositivo de intercambio de calor, han captado la atención de la comunidad de transferencia de calor debido a su sencilla estructura, alta confiabilidad y eficaz capacidad de transferencia de calor, los tubos de calor se han convertido en una elección común en la gestión térmica de dispositivos electrónicos de alta potencia.
        
        \end{enumerate}
        
\end{enumerate}
\end{enumerate}

\needspace{4cm}
\subsubsection{Comparación de Productos Relacionados}
Se revisó una serie de cámaras inteligentes con características interesantes para el desarrollo del producto planteado, se puede apreciar a las mismas en las Figuras \ref{fig:EZVIC_C2C} a \ref{fig:ReolinkArgusP}.

\begin{enumerate}[label=\alph*)]
    \needspace{3cm}
    \item EZVIZ C2C
    
    \begin{figure}[H]
    \centering
    \begin{adjustbox}{width=\linewidth/2}
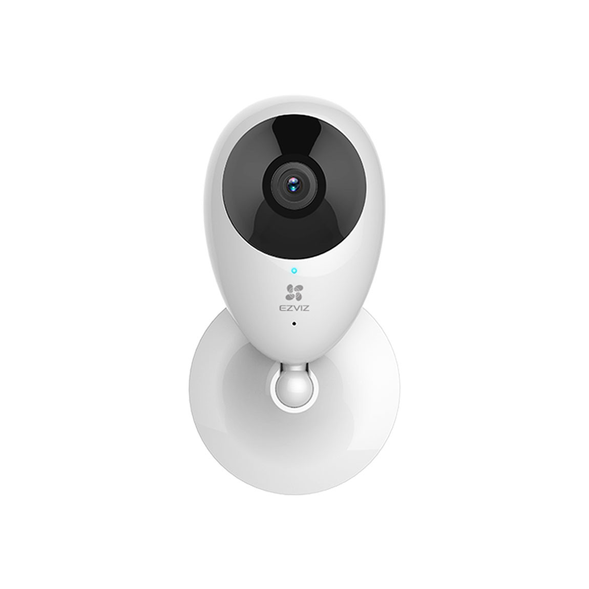
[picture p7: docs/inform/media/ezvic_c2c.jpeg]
      
    \end{adjustbox}
    \caption{\label{fig:EZVIC_C2C}Cámara inteligente EZVIC C2C.}
    \end{figure}
    
    La cámara presente en la Figura \ref{fig:EZVIC_C2C}, está diseñada para una instalación rápida y sencilla gracias a su base magnética(\cite{EZVIZ}). Desventaja: No tiene movimiento automático, depende del usuario o transeúnte.

    \needspace{3cm}
    \item Imou

    \begin{figure}[H]
    \centering
    \begin{adjustbox}{width=\linewidth/4}
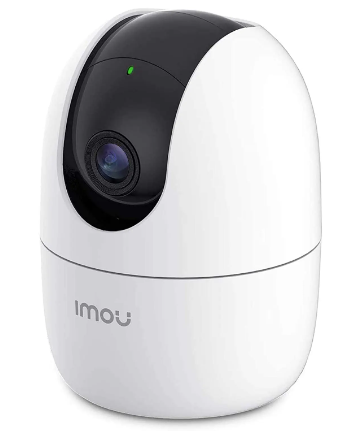
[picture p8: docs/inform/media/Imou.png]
          
    \end{adjustbox}
    \caption{\label{fig:Imou}Cámara inteligente Imou.}
    \end{figure}

    Una de las características más destacables de este producto es que su cámara con sensor de movimiento es capaz de detectar cualquier intrusión en segundos, realizar un seguimiento automático de la actividad y grabar vídeos en tiempo real. 

    \needspace{3cm}
    \item Xiaomi Domo

    \begin{figure}[H]
    \centering
    \begin{adjustbox}{width=\linewidth/4}
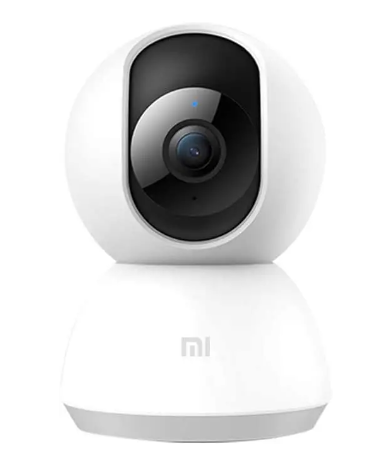
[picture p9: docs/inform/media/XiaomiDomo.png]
      
    \end{adjustbox}
    \caption{Cámara inteligente Xiaomi Domo.}
    \label{fig:XiamiDomo}
    \end{figure}

    La cámara cuenta con un rango de rotación horizontal de 360º y vertical de 96º. 
    Tiene motores duales silenciosos, los lentes de la cámara rotan en completo silencio para pasar inadvertida hasta en las horas de sueño profundo. De hecho, esta cámara puede instalarse de lado, en posición invertida o sencillamente sobre un estante, puesto que su base es sólida e incluye tornillos para un ajuste firme.

    \needspace{3cm}
    \item Reolink Argus P

    \begin{figure}[H]
    \centering
    \begin{adjustbox}{width=\linewidth/2}
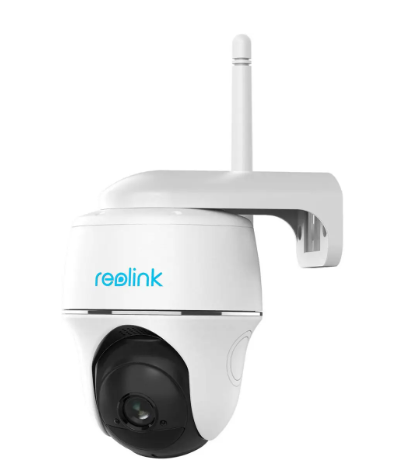
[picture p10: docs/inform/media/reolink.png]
      
    \end{adjustbox}
    \caption{\label{fig:ReolinkArgusP}Cámara inteligente Reolink Argus P.}
    \end{figure}

    Ofrece un amplio ángulo de visión puesto que su lente gira 355º en sentido horizontal y 140º verticalmente.
    
\end{enumerate}

\needspace{5cm}
\subsection{Búsqueda Interna}
\begin{enumerate}[label=\alph*)]

\item \textbf {Administración de energía:} Diseño de un sistema de administración de energía eficiente que permita un funcionamiento continuo en interiores y la recarga de baterías cuando sea necesario.
    \begin{itemize}
    \item Uso de paneles solares para cargar las baterías y proporcionar energía sostenible.
    \item Incorporación de una función de ahorro de energía que apague automáticamente la detección cuando no se detecta actividad de fumado durante un período prolongado.
    \item Posibilidad de alimentación a través de la red eléctrica para su uso en lugares donde haya acceso a tomas de corriente.
    \end{itemize}

\item \textbf{Sistema de movimiento:} Desarrollo de un sistema de orientación de cámara con movimientos suaves y discretos para evitar molestar a las personas en interiores.
    \begin{itemize}
    \item Uso de sensores de proximidad para garantizar que la cámara no colisione con objetos o paredes mientras se ajusta para obtener una vista óptima.
    \item Implementación de un modo de seguimiento silencioso que minimice cualquier ruido mecánico al seguir a una persona fumando.
    \item Diseño de un mecanismo de montaje versátil que permita la instalación en techos, paredes o esquinas de interiores.
    \end{itemize}

\item \textbf{Gestión Térmica:} Diseño de conductos de aire ajustables que permitan direccionar el flujo de aire hacia las áreas donde se detecta actividad de fumado en interiores.
    \begin{itemize}
    \item Integración de ventiladores de baja sonoridad para mantener un ambiente tranquilo y cómodo en lugares cerrados.
    \item Uso de sensores de temperatura y humedad para ajustar la velocidad y dirección del flujo de aire de acuerdo con las condiciones ambientales.
    \item Desarrollo de una carcasa compacta y estética que se integre de manera discreta en entornos interiores.
    \item Diseño de generadores de vórtices para maximizar la entropía en los conductos de ventilación, sabiendo que la entropía maximiza la disipación del calor.
    \end{itemize}
\end{enumerate}

    \needspace{3cm}
    \subsection{Exploración Sistemática}
    
    \subsubsection{Árbol de Clasificación}

    \begin{figure}[H]
        \centering
        \resizebox{0.5\linewidth}{!}{
            \begin{tikzpicture}[mindmap, grow cyclic, every node/.style=concept, concept color=olive!40,
                level 1/.append style={level distance=6cm,sibling angle=100},
                level 2/.append style={level distance=3cm,sibling angle=39},
            ]
            % Root concept
            \node[concept] {Distribucion de Energia}
            child [concept color=red!40] {
                node[concept] {Gestión de Cables}
                child { node[concept] {Arandelas} }
                child { node[concept] {Clips} }
                child { node[concept] {Correas} }
                child { node[concept] {Monturas para Correas} }
                child { node[concept] {Envolturas y Fundas} }
                child { node[concept] {Glandes} }
                child { node[concept] {Tubos termoretráctiles} }
                child { node[concept] {Correas de torsión} }
                child { node[concept] {Abrazaderas} }
            }
            child [concept color=teal!40, level distance=4.2cm] {
                node[concept] {Selección de Baterías}
                child { node[concept] {Alcalinas} }
                child { node[concept] {De botón} }
                child { node[concept] {Plomo-Acido} }
                child { node[concept] {NiCd} }
                child { node[concept] {NiMH} }
                child { node[concept] {Li-Ion} }
            };
        \end{tikzpicture}
        }
        \caption{Árbol de clasificación para los fragmentos de concepto del sistema de conversión de energía.}
        \label{fig:arbolEnergia}
    \end{figure}

    El diagrama de la Figura \ref{fig:arbolEnergia} muestra una jerarquía de conceptos relacionados con la "Distribución de Energía". Hay dos categorías principales: "Gestión de Cables" en azul y "Selección de Baterías" en verde. "Gestión de Cables" se desglosa en subconceptos como "Protección de Cables" y "Orientación de Cables", mientras que "Selección de Baterías" incluye "Tipo de Batería" y "Capacidad y Duración". Este gráfico ayuda a comprender los elementos clave de un sistema de distribución de energía.
    
    \begin{figure}[H]
    \centering
    \resizebox{0.6\linewidth}{!}{
    \begin{tikzpicture}[mindmap, grow cyclic, every node/.style=concept, concept color=red!40,
        level 1/.append style={level distance=5cm,sibling angle=90},
        level 2/.append style={level distance=4cm,sibling angle=45},
        ]
        % Root concept
        \node[concept] {Sistemas de Movimiento}
        child [concept color=orange!40, level distance=4.5cm] {
            node[concept] {Selección de Motor}
            child { node[concept] {Motor DC} }
            child { node[concept] {Motor Brushless} }
            child { node[concept] {Motor a Paso} }
            child { node[concept] {Servomotor} }
        }
        child [concept color=magenta!40, level distance=5.4cm] {
            node[concept] {Generadores de Movimiento Panorámico y de Inclinación (PTMG)}
            child { node[concept] {Tren de Engranes Cónicos} }
            child { node[concept] {Juntas Homocinéticas} }
            child { node[concept] {Mecanismo de Cinco Barras} }
            child { node[concept] {Enlace Esférico} }
            child { node[concept] {Tren de Engranes Diferencial} }
            child { node[concept] {Mecanismo de Hervé} }
        };
    \end{tikzpicture}
    }
    \caption{\label{fig:arbolClasificacionMovimiento} Árbol de clasificación para los fragmentos de concepto del sistema de transformación de movimiento.}
    \label{fig:arbolMovimiento}
    \end{figure}

    El gráfico de la Figura \ref{fig:arbolMovimiento} muestra una estructura jerárquica de conceptos relacionados con sistemas de movimiento. En la raíz, está "Sistemas de Movimiento", que se divide en dos categorías principales: "Selección de Motor" y "Generadores de Movimiento Panorámico y de Inclinación (PTMG)". Cada categoría tiene subconceptos específicos. Por ejemplo, en "Selección de Motor", se incluyen "Motor DC", "Motor Brushless", "Motor a Paso" y "Servomotor". Mientras que en "Generadores de Movimiento Panorámico y de Inclinación (PTMG)", se presentan conceptos como "Tren de Engranes Cónicos" y otros.

    \begin{figure}[H]
    \centering
    \resizebox{0.6\linewidth}{!}{
    \begin{tikzpicture}[mindmap, grow cyclic, every node/.style=concept, concept color=violet!40,
        level 1/.append style={level distance=5cm,sibling angle=65}, % Growing upward
        level 2/.append style={level distance=4.2cm,sibling angle=50},
    ]
    % Root concept
    \node[concept] {Gestión Térmica}
        child [concept color=blue!40] { 
            node[concept] {Ventilación de Aire de adelante hacia atrás}
            child { node[concept] {Ventiladores en la Parte Trasera} }
            child { node[concept] {Montaje Horizontal de Placas Electrónicas} }
            child { node[concept] {Montaje Vertical de Placas Electrónicas} }
            child { node[concept] {Ventiladores Directamente Encima de las Placas Electrónicas:} }
        }
        child [concept color=cyan!40] { 
            node[concept] {Indirecta} 
            child { node[concept] {Canales de Refrigeración} }
            child { node[concept] {Tubo de calor} }
        };
    \end{tikzpicture}
    }
    \caption{Árbol de clasificación para los fragmentos de concepto del sistema de gestión térmica.}
    \label{fig:arbolAire}
    \end{figure}

    El diagrama de la figura \ref{fig:arbolAire} representa una jerarquía de conceptos relacionados con el "Direccionamiento de Aire". En la raíz del árbol se encuentra este concepto principal, que se divide en cuatro subconceptos: "Optimización de Diseño", "Canal de Refrigeración", "Geometría Compleja" y "Enfriamiento Uniforme". Este gráfico proporciona una estructura visual para comprender los aspectos clave del sistema de gestión térmica.
    
    \needspace{2.5cm}
    \subsubsection{Tablas de Combinación}

    \begin{table}[H]
    \centering
    \begin{tabularx}{\textwidth}{|X|X|X|X|X|}
    \hline
    \textbf{Convertir Energía Eléctrica en Energía Mecánica} & \textbf{Aplicar Energía Mecánica al Mecanismo} & \textbf{Selección de Baterías} & \textbf{Gestión de Cables} & \textbf{Gestion Termica} \\
    \hline
    Motor paso a paso & Mecanismo de Hervé & \cellcolor{green}Li-Ion  & Arandelas & Tubo de calor\\
    \hline
    \cellcolor{green}Motor Brushless & \cellcolor{green}Tren de engranes diferencial & NiMH & Clips & Canales de Refrigeracion \\
    \hline
    Motor DC & Enlace Esférico & NiCd & Correas & \cellcolor{green}Ventiladores encima de las placas electronicas\\
    \hline
    Servomotor & Mecanismo de cinco barras & Plomo-Acido & Monturas para correas & Montaje vertical de las placas electronicas\\
    \hline
     & Juntas Homocinéticas & De boton & Encolturas y fundas & Montaje Horizontal de las placas electronicas\\
    \hline
     & Tren de Engranes Cónicos & Alcalinas & Glandes & Ventiladores en la parte trasera\\
    \hline
     & & & \cellcolor{green}Abrazadera para cables & \\
    \hline
     & & & Tubos termoretractiles & \\
    \hline
     & & & Correas de torsion & \\
    \hline
    \end{tabularx}
    \caption{Tabla de Combinación 1}
    \label{tab:combinacion_1}
    \end{table}

    En el Cuadro \ref{tab:combinacion_1}, se presenta una solución elegante que combina un motor brushless con el sofisticado mecanismo de un tren de engranes diferencial. Esta configuración es alimentada por baterías Li-Ion, y la organización ordenada de los cables mediante abrazaderas asegura un aspecto limpio y profesional. Además, se han incorporado ventiladores estratégicamente ubicados encima de las placas electrónicas para disipar el calor.
    
    \begin{table}[H]
    \centering
    \begin{tabularx}{\textwidth}{|X|X|X|X|X|}
    \hline
    \textbf{Convertir Energía Eléctrica en Energía Mecánica} & \textbf{Aplicar Energía Mecánica al Mecanismo} & \textbf{Selección de Baterías} & \textbf{Gestión de Cables} & \textbf{Gestion Termica} \\
    \hline
    Motor paso a paso & Mecanismo de Hervé & \cellcolor{green}Li-Ion  & Arandelas & Tubo de calor\\
    \hline
    Motor Brushless & Tren de engranes diferencial & NiMH & Clips & Canales de Refrigeracion \\
    \hline
    Motor DC & Enlace Esférico & NiCd & Correas & \cellcolor{green}Ventiladores encima de las placas electronicas\\
    \hline
    \cellcolor{green}Servomotor & Mecanismo de cinco barras & Plomo-Acido & Monturas para correas & Montaje vertical de las placas electronicas\\
    \hline
     & Juntas Homocinéticas & De boton & Encolturas y fundas & Montaje Horizontal de las placas electronicas\\
    \hline
     & \cellcolor{green}Tren de Engranes Cónicos & Alcalinas & Glandes & Ventiladores en la parte trasera\\
    \hline
     & & & \cellcolor{green}Abrazadera para cables & \\
    \hline
     & & & Tubos termoretractiles & \\
    \hline
     & & & Correas de torsion & \\
    \hline
    \end{tabularx}
    \caption{Tabla de Combinación 2}
    \label{tab:combinacion_2}
    \end{table}

    El Cuadro \ref{tab:combinacion_2} muestra una solución que combina un servomotor con un tren de engranes cónicos. Se alimenta con baterías Li-Ion y utiliza abrazaderas para mantener los cables organizados. Además, se han colocado ventiladores sobre las placas electrónicas para reducir la temperatura.

    \begin{table}[H]
    \centering
    \begin{tabularx}{\textwidth}{|X|X|X|X|X|}
    \hline
    \textbf{Convertir Energía Eléctrica en Energía Mecánica} & \textbf{Aplicar Energía Mecánica al Mecanismo} & \textbf{Selección de Baterías} & \textbf{Gestión de Cables} & \textbf{Gestion Termica} \\
    \hline
    Motor paso a paso & Mecanismo de Hervé & \cellcolor{green}Li-Ion  & Arandelas & Tubo de calor\\
    \hline
    Motor Brushless & \cellcolor{green}Tren de engranes diferencial & NiMH & Clips & Canales de Refrigeracion \\
    \hline
    \cellcolor{green}Motor DC & Enlace Esférico & NiCd & Correas & \cellcolor{green}Ventiladores encima de las placas electronicas\\
    \hline
    Servomotor & Mecanismo de cinco barras & Plomo-Acido & Monturas para correas & Montaje vertical de las placas electronicas\\
    \hline
     & Juntas Homocinéticas & De boton & Encolturas y fundas & Montaje Horizontal de las placas electronicas\\
    \hline
     & Tren de Engranes Cónicos & Alcalinas & Glandes & Ventiladores en la parte trasera\\
    \hline
     & & & \cellcolor{green}Abrazadera para cables & \\
    \hline
     & & & Tubos termoretractiles & \\
    \hline
     & & & Correas de torsion & \\
    \hline
    \end{tabularx}
    \caption{Tabla de Combinación 3}
    \label{tab:combinacion_3}
    \end{table}    

    El Cuadro \ref{tab:combinacion_3} muestra una solución que combina un motor de corriente continua con un tren de engranes diferencial. Se alimenta con baterías Li-Ion y utiliza abrazaderas para mantener los cables organizados. Además, se han colocado ventiladores sobre las placas electrónicas para disipar el calor.

    \begin{table}[H]
    \centering
    \begin{tabularx}{\textwidth}{|X|X|X|X|X|}
    \hline
    \textbf{Convertir Energía Eléctrica en Energía Mecánica} & \textbf{Aplicar Energía Mecánica al Mecanismo} & \textbf{Selección de Baterías} & \textbf{Gestión de Cables} & \textbf{Gestion Termica} \\
    \hline
    \cellcolor{green}Motor paso a paso & Mecanismo de Hervé & \cellcolor{green}Li-Ion  & Arandelas & Tubo de calor\\
    \hline
    Motor Brushless & Tren de engranes diferencial & NiMH & Clips & \cellcolor{green}Canales de Refrigeracion \\
    \hline
    Motor DC & Enlace Esférico & NiCd & \cellcolor{green}Correas & Ventiladores encima de las placas electronicas\\
    \hline
    Servomotor & Mecanismo de cinco barras & Plomo-Acido & Monturas para correas & Montaje vertical de las placas electronicas\\
    \hline
     & Juntas Homocinéticas & De boton & Encolturas y fundas & Montaje Horizontal de las placas electronicas\\
    \hline
     & \cellcolor{green}Tren de Engranes Cónicos & Alcalinas & Glandes & Ventiladores en la parte trasera\\
    \hline
     & & & Abrazadera para cables & \\
    \hline
     & & & Tubos termoretractiles & \\
    \hline
     & & & Correas de torsion & \\
    \hline
    \end{tabularx}
    \caption{Tabla de Combinación 4}
    \label{tab:combinacion_4}
    \end{table} 

    El Cuadro \ref{tab:combinacion_4} muestra una solución que combina un motor paso a paso con un tren de engranes conicos. Se alimenta con baterías Li-Ion y utiliza correas para mantener los cables organizados. Además, se incorpora canales de refrigeracion para difundir el calor.

    \begin{table}[H]
    \centering
    \begin{tabularx}{\textwidth}{|X|X|X|X|X|}
    \hline
    \textbf{Convertir Energía Eléctrica en Energía Mecánica} & \textbf{Aplicar Energía Mecánica al Mecanismo} & \textbf{Selección de Baterías} & \textbf{Gestión de Cables} & \textbf{Gestion Termica} \\
    \hline
    Motor paso a paso & Mecanismo de Hervé & Li-Ion  & Arandelas & Tubo de calor\\
    \hline
    Motor Brushless & Tren de engranes diferencial & NiMH & Clips & Canales de Refrigeracion \\
    \hline
    Motor DC & Enlace Esférico & NiCd & Correas & Ventiladores encima de las placas electronicas\\
    \hline
    \cellcolor{green}Servomotor & \cellcolor{green}Mecanismo de cinco barras & \cellcolor{green}Plomo-Acido & Monturas para correas & Montaje vertical de las placas electronicas\\
    \hline
     & Juntas Homocinéticas & De boton & Encolturas y fundas & Montaje Horizontal de las placas electronicas\\
    \hline
     & Tren de Engranes Cónicos & Alcalinas & Glandes & \cellcolor{green}Ventiladores en la parte trasera\\
    \hline
     & & & Abrazadera para cables & \\
    \hline
     & & & \cellcolor{green}Tubos termoretractiles & \\
    \hline
     & & & Correas de torsion & \\
    \hline
    \end{tabularx}
    \caption{Tabla de Combinación 5}
    \label{tab:combinacion_5}
    \end{table} 

    El Cuadro \ref{tab:combinacion_5} muestra una solución que combina un servomotor con un mecanimso de cinco barras. Se alimenta con baterías Plomo-Acido y utiliza tubos termoretractiles para mantener los cables organizados y seguros. Además, se incorpora ventiladores en la parte trasera para evacuar el calor.

    \begin{table}[H]
    \centering
    \begin{tabularx}{\textwidth}{|X|X|X|X|X|}
    \hline
    \textbf{Convertir Energía Eléctrica en Energía Mecánica} & \textbf{Aplicar Energía Mecánica al Mecanismo} & \textbf{Selección de Baterías} & \textbf{Gestión de Cables} & \textbf{Gestion Termica} \\
    \hline
    Motor paso a paso & \cellcolor{green}Mecanismo de Hervé & \cellcolor{green}Li-Ion  & Arandelas & Tubo de calor\\
    \hline
    Motor Brushless & Tren de engranes diferencial & NiMH & Clips & Canales de Refrigeracion \\
    \hline
    \cellcolor{green}Motor DC & Enlace Esférico & NiCd & \cellcolor{green}Correas & Ventiladores encima de las placas electronicas\\
    \hline
    Servomotor & Mecanismo de cinco barras & Plomo-Acido & Monturas para correas & Montaje vertical de las placas electronicas\\
    \hline
     & Juntas Homocinéticas & De boton & Encolturas y fundas & Montaje Horizontal de las placas electronicas\\
    \hline
     & Tren de Engranes Cónicos & Alcalinas & Glandes & \cellcolor{green}Ventiladores en la parte trasera\\
    \hline
     & & & Abrazadera para cables & \\
    \hline
     & & & Tubos termoretractiles & \\
    \hline
     & & & Correas de torsion & \\
    \hline
    \end{tabularx}
    \caption{Tabla de Combinación 6}
    \label{tab:combinacion_6}
    \end{table} 

    El Cuadro \ref{tab:combinacion_6} muestra una solución que combina un motor de corriente continua con un mecanimso de Hervé. Se alimenta con baterías de Li-Ion y utiliza tubos correas para cables, manteniendo en orden el cableado interno. Además, se incorpora ventiladores en la parte trasera para evacuar el calor.

\needspace{3cm}
\subsection{Análisis de Soluciones}
\subsubsection{Explorar el espacio de solucion}
    Dentro del marco de este proyecto, se llevó a cabo una exhaustiva exploración de diversas soluciones destinadas a abordar las problemáticas planteadas. Cada una de estas opciones se describe con detalle en este informe. A medida que avanzaba la investigación, se recibía retroalimentación que aportaba nuevas ideas para investigar y ayudaba a descartar las soluciones menos eficientes. Este enfoque de refinamiento constante ha contribuido a la evolución y optimización de las estrategias, asegurando que cada elección esté respaldada por un análisis riguroso y contribuya al éxito global del proyecto.
\subsubsection{Revisar alternativa}
    Dentro del ámbito de este proyecto, se llevó a cabo una meticulosa revisión de alternativas con el objetivo de abordar las problemáticas planteadas. Este informe presenta un análisis exhaustivo de cada una de las opciones consideradas. En el transcurso de la investigación, surgieron preguntas fundamentales, como si existían diagramas funcionales alternativos o si era posible una descomposición del problema desde enfoques diferentes. Esta perspicaz línea de indagación permitió explorar nuevas vías que podrían conducir a soluciones potencialmente más eficaces. El proceso de revisión constante, en combinación con un análisis crítico y creativo, ha sido esencial para refinar y optimizar nuestras estrategias, garantizando que cada elección se base en una evaluación sólida y contribuya al éxito global del proyecto.
\subsubsection{Considerar fuentes externas}
    Dentro del contexto de este proyecto, se ha llevado a cabo una exhaustiva evaluación de fuentes externas pertinentes, incluyendo literatura técnica e investigaciones previas. Esta revisión meticulosa ha permitido enriquecer las soluciones propuestas y tomar decisiones más sólidas y fundamentadas. El proceso de consideración de fuentes externas ha sido esencial para optimizar las estrategias, asegurando que cada elección esté respaldada por una base de conocimiento sólida y contribuya al éxito general del proyecto.
\subsubsection{Integrar ideas}
    Dentro del marco de este proyecto, se ha puesto un especial énfasis en la integración de ideas y contribuciones de todo el equipo. Cada idea, aportación y perspectiva ha sido considerada de manera meticulosa y se ha trabajado de forma efectiva para su incorporación adecuada en el proceso. La colaboración constante y la comunicación efectiva entre los miembros del equipo han sido fundamentales en este paso, asegurando que todas las voces sean escuchadas y que las ideas se integren de manera armoniosa y productiva.

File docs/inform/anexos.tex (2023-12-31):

\newpage
\needspace{3cm}
{\huge \textbf{ANEXOS}}

\section*{Calendario}
\input{calendario}

\includepdf[pages=-, fitpaper]{anexos/planos.pdf}

%\newpage
%\section*{Encuesta}
%\input{encuesta}

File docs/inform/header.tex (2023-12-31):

%\usepackage[mathletters]{ucs}
\usepackage[backend=biber,style=apa]{biblatex}
\addbibresource{references.bib} %Imports bibliography file
% Language setting
% Replace `english' with e.g. `spanish' to change the document language
\usepackage[spanish]{babel}
% Set page size and margins
\usepackage[a4paper,top=2cm,bottom=2cm,left=3cm,right=3cm,marginparwidth=1.75cm, headheight=64pt]{geometry}
\usepackage{mathptmx}
\usepackage{amsmath}
\usepackage{amsfonts}
\usepackage{amssymb}
\usepackage[T1]{fontenc}
\usepackage{gentium}
\usepackage{float}
\usepackage{termcal}
\usepackage[table]{xcolor}
\usepackage{needspace}
\usepackage{titlesec}
\usepackage{enumitem}
\usepackage{graphicx} % Required for inserting images
\usepackage{wrapfig}
\usepackage{enumitem}
\usepackage{fancyhdr}
\usepackage{float}
\usepackage{eurosym}
\usepackage{color}
\usepackage{titling}
\usepackage{lipsum}
\usepackage{tocbibind}
\usepackage{datetime2}
\usepackage[colorlinks=true,linkcolor=black,anchorcolor=black,citecolor=black,filecolor=black,menucolor=black,runcolor=black,urlcolor=black]{hyperref}
%tikz image
\usepackage{amsmath}
\usepackage{color,pxfonts,fix-cm}
\usepackage{latexsym}
\usepackage{pict2e}
\usepackage{wasysym}
\usepackage{tikz}
\usetikzlibrary{mindmap, trees}
\usepackage{adjustbox}
\usepackage{tabularx}
\usepackage{ragged2e}
\usepackage{csquotes}
\usepackage{pdfpages}

% Set section and subsection titles to font size 12
\titleformat*{\section}{\normalfont\fontsize{12}{14}\bfseries}
\titleformat*{\subsection}{\normalfont\fontsize{12}{14}\bfseries}

%%% Para las cabeceras
\newcommand{\hsp}{\hspace{20pt}}
\newcommand{\HRule}{\rule{\linewidth}{0.5mm}}
\headheight=50pt

\newcommand{\vacio}{\textcolor{white}{UCB-SC}}

%\DTMlangsetup[es-ES]

\title{Smoke Detector Cam}
\author{
    Leonardo Achá Boiano \\
    Bruno Ramiro Rejas Montero}

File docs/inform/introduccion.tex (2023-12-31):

El presente informe tiene como objetivo presentar la propuesta del proyecto "Smoke Detector Cam". Este proyecto tiene como finalidad desarrollar un sistema inteligente basado en una cámara con capacidad de detección de humo y fuego para contribuir a la prevención y mitigación de incendios, así como para promover ambientes libres de humo de tabaco, en cumplimiento con la recientemente promulgada ley de control del tabaco en Bolivia.

\needspace{3cm}
\subsection{Antecedentes del problema}
\input{antecedentes}

\needspace{3cm}
\subsection{Identificación del problema}

El tabaquismo representa un grave problema de salud pública en Bolivia, con un alto número de fumadores y personas expuestas al humo de segunda mano. Es esencial implementar medidas efectivas para asegurar ambientes libres de humo y promover el cumplimiento de la ley de control del tabaco.

\needspace{4cm}
\subsection{Justificación} 
\input{justificacion}

\needspace{3cm}
\subsection{Detalle mínimo de la propuesta}
\input{detalle_minimo}

\needspace{3cm}
\subsection{Boceto inicial de la propuesta}
\input{boceto_inicial}

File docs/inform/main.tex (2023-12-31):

\documentclass[letterpaper,12pt]{article} 
\usepackage[utf8]{inputenc}
\input{header}

\begin{document}

\input{portada}

\needspace{3cm}
\section{Introducción}
\input{introduccion}

\needspace{3cm}
\section{Objetivos}
\input{objetivos}

\needspace{3cm}
\section{Generación de Conceptos}
\input{generacion_de_conceptos}

\needspace{6cm}
\section{Filtrado de Conceptos}
\input{filtrado_de_conceptos}

\needspace{6cm}
\section{Prototipos Realizados}
\input{prototipos_realizados}

%\needspace{2cm}
\section{Simulaciones}
\subsection{Análisis Estático}
\input{analisis_estatico}
\subsection{Estudio de Diseño}
\input{estudio_de_diseño}

\needspace{6cm}
\section{Recomendaciones}
\input{recomendaciones}

\needspace{6cm}
\section{Conclusiones}
\input{conclusiones}

\newpage
\printbibliography

\input{anexos}

\end{document}

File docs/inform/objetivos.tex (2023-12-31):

El proyecto "Smoke Detector Cam" tiene los siguientes objetivos:

\subsection{Objetivo General}
Desarrollar el mecanismo de movimiento del sistema embebido "Smoke Detector Cam" para la detección temprana de humo y fuego en ambientes cerrados, con el propósito de contribuir a la prevención y mitigación de incendios y promover ambientes libres de humo de tabaco en cumplimiento de la ley de control del tabaco en Bolivia.

\needspace{3cm}
\subsection{Objetivos Específicos}
\begin{itemize}
\item Desarrollar "Smoke Detector Cam" con sensores de humo, cámara, refrigeración y batería, teniendo en cuenta limitaciones de espacio y fabricación.
\item Crear el cuerpo de la cámara con software CAD para impresión 3D a gran escala, enfocándose en resistencia, durabilidad y adaptabilidad a diferentes entornos cerrados.
\item Simular el sistema de refrigeración planificado para garantizar el correcto funcionamiento de los componentes electrónicos sin afectar la apariencia visual, utilizando herramientas de análisis de ingeniería asistida por computadora (CAE).
\needspace{4cm}
\item Aplicar el método de gestión de proyectos de cinco pasos de la literatura académica (\cite{Ulrich2012}), que incluye identificar oportunidades, evaluar proyectos, asignar recursos y tiempo, finalizar la planificación del anteproyecto y reflexionar sobre los resultados y el proceso.
\end{itemize}

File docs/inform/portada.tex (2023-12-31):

\begin{titlepage}
\begin{center}
\vspace{1.5cm}
{\fontsize{16}{6}\selectfont{\textbf{UNIVERSIDAD CATÓLICA BOLIVIANA "SAN PABLO"}}}\\
[1em]
{\fontsize{14}{5}\selectfont{\textbf{UNIDAD ACADÉMICA REGIONAL SANTA CRUZ}}}\\
[1em]
{\fontsize{12}{5}\selectfont{\textbf{Carrera Ing. Mecatrónica}}}\\
[2.6cm]
% Título del trabajo
\textcolor{black}
{\fontsize{16}{6}\selectfont{\textsc{\thetitle}}}\\
%{\Huge\textbf{\thetitle}}\\
[1cm]
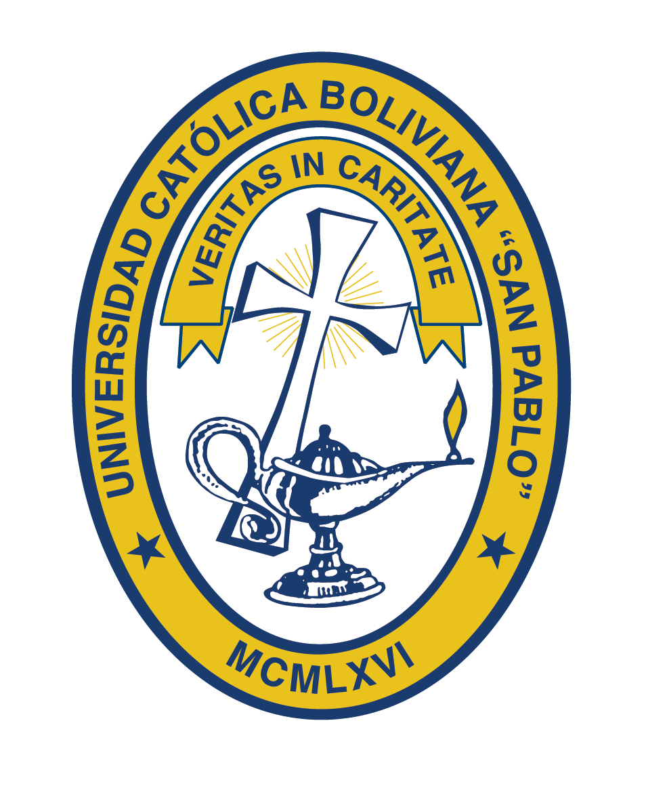
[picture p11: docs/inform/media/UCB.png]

\\%[2cm]
% Autor(es) del trabajo de investigación
\textcolor{black}{\fontsize{14}{5}\selectfont{\theauthor}}\\
[1cm]
% Docente guia del trabajo de investigación
{\fontsize{14}{5}\selectfont{Docente: Ing. Daniel Raul Asturizaga Hurtado De Mendoza}}\\
{\fontsize{14}{5}\selectfont{Docente: Ing. José Jesús Cabrera Pantoja}}\\
[2cm]
{\fontsize{12}{5}\selectfont{Santa Cruz - Bolivia}}\\
{\fontsize{12}{5}\selectfont{\DTMtoday}}\\
[4cm]
\end{center}
\end{titlepage}

\newpage

\renewcommand{\headrulewidth}{0.5pt}
\fancyhead[R]{
	\textcolor{black}{\fontsize{10}{4}\selectfont{\textbf{\thetitle}}}}
\fancyhead[L]{\vacio}

\renewcommand{\footrulewidth}{0.5pt}
\fancyfoot[L]{\footnotesize UCB - \materia}
\fancyfoot[C]{\vacio}
\fancyfoot[R]{\footnotesize Página \thepage}

\newpage
\tableofcontents

%\newpage
%\listoffigures

%\newpage
%\listoftables

\newpage

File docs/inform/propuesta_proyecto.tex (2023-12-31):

\documentclass[letterpaper,12pt]{article} 
\usepackage[utf8]{inputenc}
\input{header}

\title{Propuesta de Proyecto:\\Smoke Detector Cam}

\begin{document}

\maketitle

\needspace{3cm}
\section{Introducción}

El presente informe tiene como objetivo presentar la propuesta del proyecto "Smoke Detector Cam". Este proyecto tiene como finalidad desarrollar un sistema inteligente basado en una cámara con capacidad de detección de humo y fuego para contribuir a la prevención y mitigación de incendios, así como para promover ambientes libres de humo de tabaco, en cumplimiento con la recientemente promulgada ley de control del tabaco en Bolivia.

\needspace{3cm}
\section{Antecedentes del problema}
\input{antecedentes}

\needspace{3cm}
\section{Identificación del problema}

El tabaquismo representa un grave problema de salud pública en Bolivia, con un alto número de fumadores y personas expuestas al humo de segunda mano. Es esencial implementar medidas efectivas para asegurar ambientes libres de humo y promover el cumplimiento de la ley de control del tabaco.

\needspace{4cm}
\section{Justificación} 
\input{justificacion}

\needspace{3cm}
\section{Objetivos}
\input{objetivos}

\needspace{3cm}
\section{Detalle mínimo de la propuesta}
\input{detalle_minimo}

\needspace{3cm}
\section{Boceto inicial de la propuesta}
\input{boceto_inicial}

\needspace{3cm}
\section{Calendario}
\input{calendario}

%\newpage
\printbibliography

\end{document}

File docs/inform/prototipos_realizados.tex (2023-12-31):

\needspace{3cm}
\subsection{Mark 0}

    \begin{figure}[H]
    \centering
    \begin{adjustbox}{width=\linewidth/2}
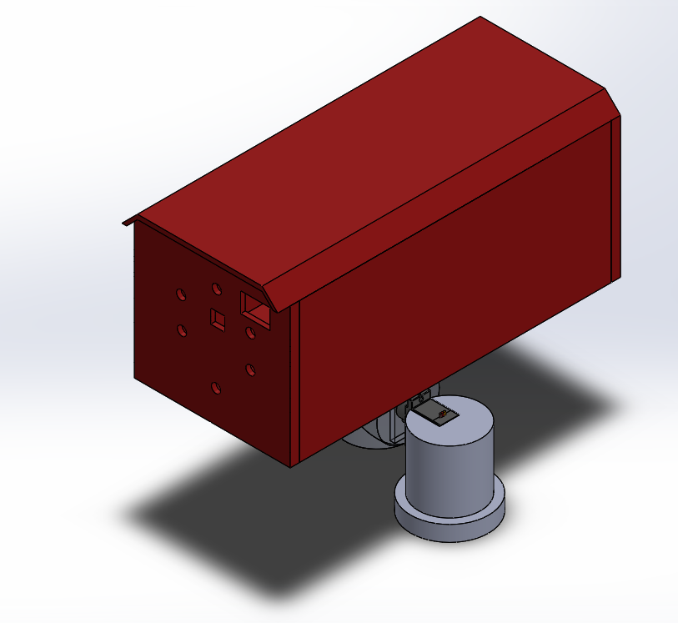
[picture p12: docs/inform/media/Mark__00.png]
      
    \end{adjustbox}
    \caption{\label{fig:isometrico_Mark00}Vista Isometrica de la version Mark 0.}
    \end{figure}
    El prototipo representado en la Figura \ref{fig:isometrico_Mark00} corresponde a la primera iteración del diseño. En esta versión inicial, se puede apreciar que la concepción original se basaba en una estructura de forma rectangular, con la placa de potencia y control ubicada en la parte frontal, incluyendo orificios específicos para alojar la ESP32-CAM y los LEDs infrarrojos. Se había contemplado la posibilidad de ubicar un ventilador en la parte trasera para proporcionar la refrigeración del sistema en su totalidad.
    \begin{figure}[H]
    \centering
    \begin{adjustbox}{width=\linewidth/2}
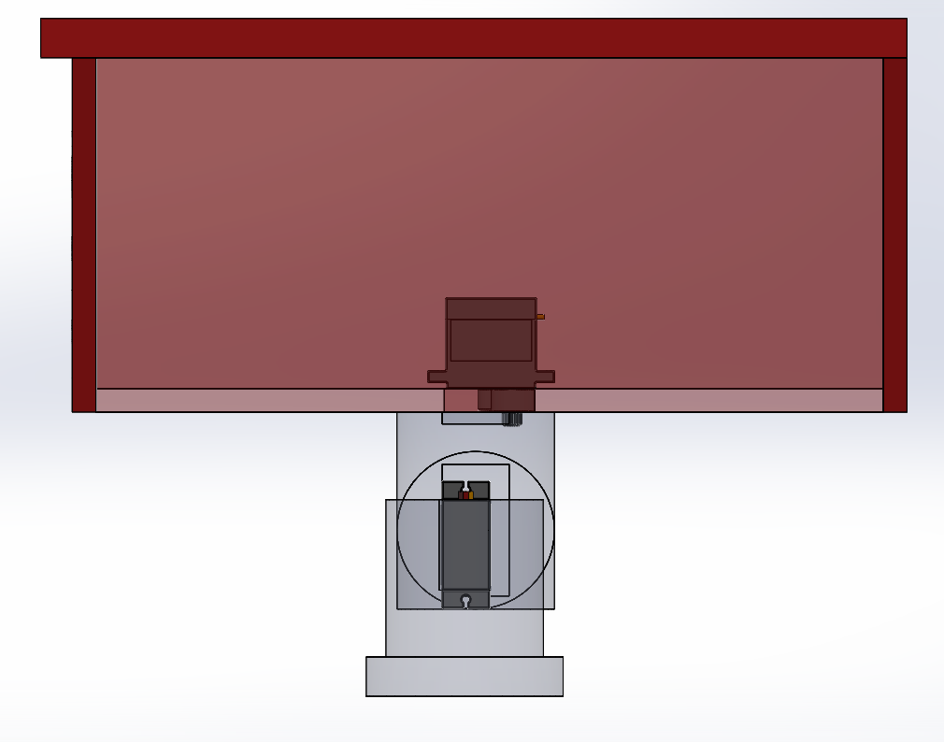
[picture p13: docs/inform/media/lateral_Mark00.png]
      
    \end{adjustbox}
    \caption{\label{fig:lateral_Mark00}Vista Lateral de la version Mark 0.}
    \end{figure}
    En la Figura \ref{fig:lateral_Mark00}, se aprecia la posición estratégica de los servomotores empleados, los cuales desempeñan un papel fundamental al posibilitar el movimiento de la cámara en los ejes X e Y. En un principio, se había contemplado la posibilidad de albergar todos los sensores y demás dispositivos electrónicos dentro de la caja; no obstante, al encontrarse en una fase de concepción temprana, esta idea no llegó a concretarse.

\needspace{3cm}
\subsection{Mark I}
    \begin{figure}[H]
    \centering
    \begin{adjustbox}{width=\linewidth/2}
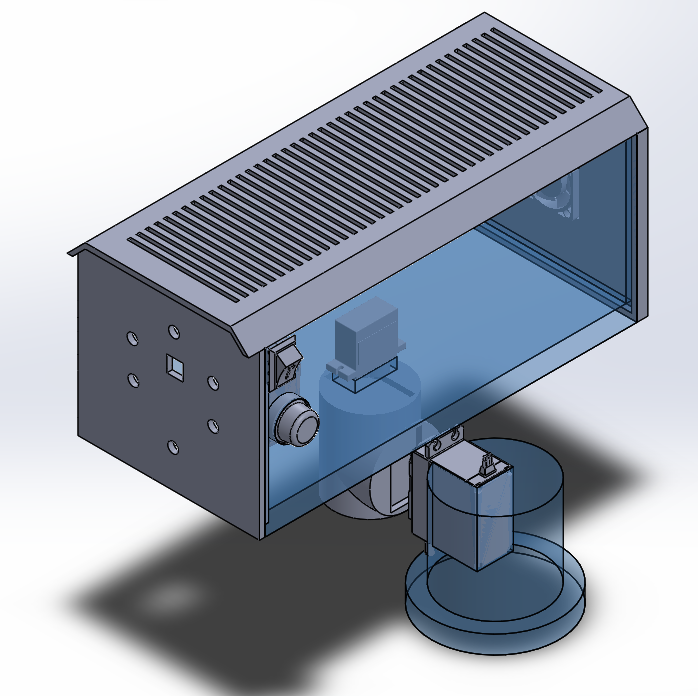
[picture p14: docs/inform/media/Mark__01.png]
      
    \end{adjustbox}
    \caption{\label{fig:isometrico_Mark01}Vista Isometrica de la version Mark I.}
    \end{figure}
     El modelo exhibido en la Figura \ref{fig:isometrico_Mark01} representa la segunda etapa de desarrollo de este diseño. En esta iteración, se observa un notable progreso al incorporar diversos componentes clave, como el ventilador, el sensor de humo y un interruptor para alimentar todo el sistema. Además, se han añadido rejillas en la parte superior de la cámara para potenciar la refrigeración del sistema. Cabe destacar que los servomotores se mantuvieron en su posición original, con sus mismos soportes, conservando su funcionalidad anterior.
     Ademas, se mantuvo la idea de colocar la placa de potencia y control en la parte delantera de la camara, con los agujeros respectivos para alojar la ESP32-CAM y los LEDs infrarrojos.

\needspace{3cm}
\subsection{Mark II}
    \begin{figure}[H]
    \centering
    \begin{adjustbox}{width=\linewidth/2}
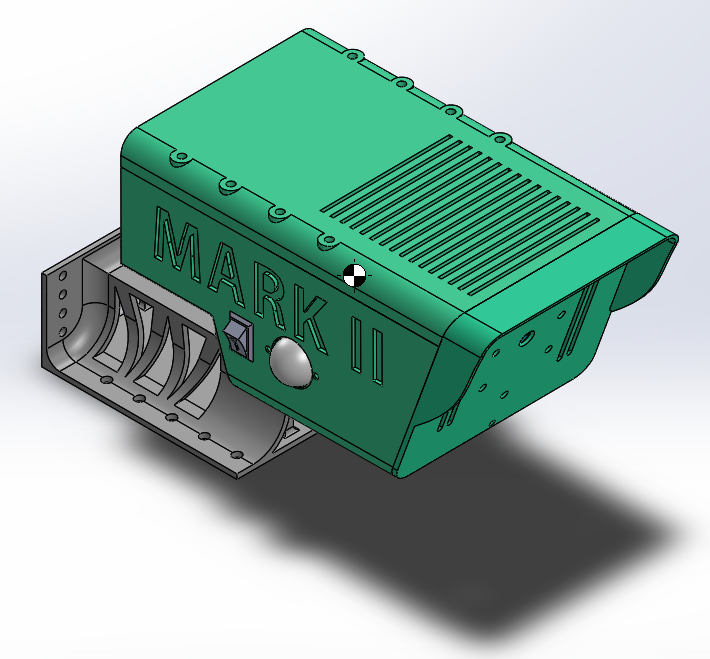
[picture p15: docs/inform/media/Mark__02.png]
      
    \end{adjustbox}
    \caption{\label{fig:isometrico_Mark02}Vista Isometrica de la version Mark II.}
    \end{figure}

    En la Figura \ref{fig:isometrico_Mark02}, se pone de manifiesto la tercera fase de evolución en el diseño. En esta iteración, destacan cambios significativos, como la reubicación de la rejilla destinada a mejorar la refrigeración, la implementación de un soporte integral para la cámara, y la configuración que permite retirar la tapa superior para acceder y manipular los componentes electrónicos internos. Además, se han añadido rejillas de menor tamaño en la tapa superior, debido al incremento en la cantidad de componentes electrónicos empleados.

    \begin{figure}[H]
    \centering
    \begin{adjustbox}{width=\linewidth/2}
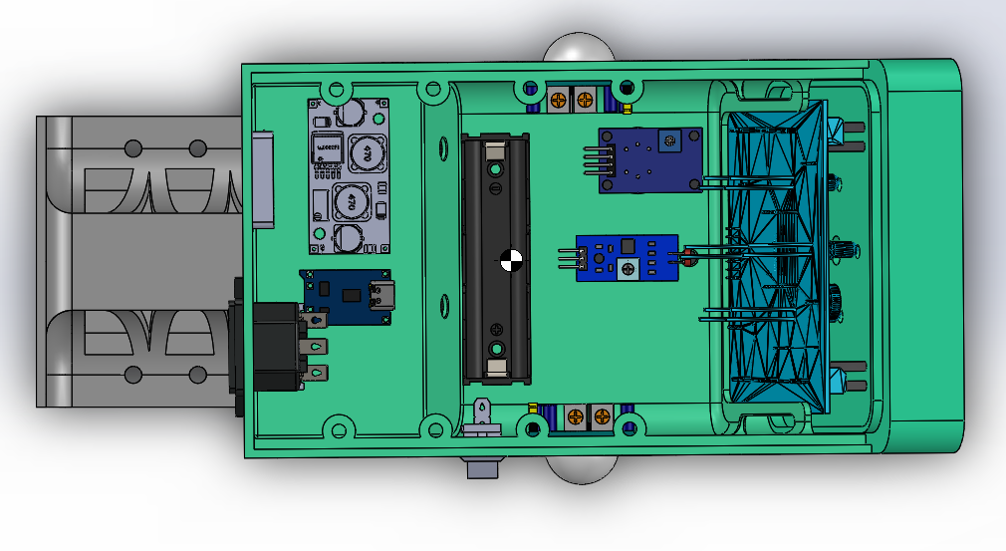
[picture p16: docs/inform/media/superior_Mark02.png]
      
    \end{adjustbox}
    \caption{\label{fig:superior_Mark02}Vista Superior de la version Mark II.}
    \end{figure}    

    En la Figura \ref{fig:superior_Mark02}, se aprecia con claridad que el modelo Mark II se estaba destacando como el vencedor, lo que impulsó la incorporación de la totalidad de los componentes electrónicos previstos. El diseño original contemplaba la posibilidad de alimentar el sistema tanto con Corriente Alterna como con una batería en caso de cortes eléctricos. Para hacerlo factible, se implementó el módulo TP4056, que permitía cargar y activar dicha batería. Asimismo, se instaló un elevador de voltaje XL6009. Todos los sensores empleados desempeñaron roles específicos en la funcionalidad del dispositivo: dos sensores PIR en los laterales para activarse ante la detección de movimiento, un sensor de humo en la parte inferior para capturar imágenes en caso de detectar humo, y un LDR para activar los LEDs infrarrojos en condiciones de baja iluminación.

    \begin{figure}[H]
    \centering
    \begin{adjustbox}{width=\linewidth/2}
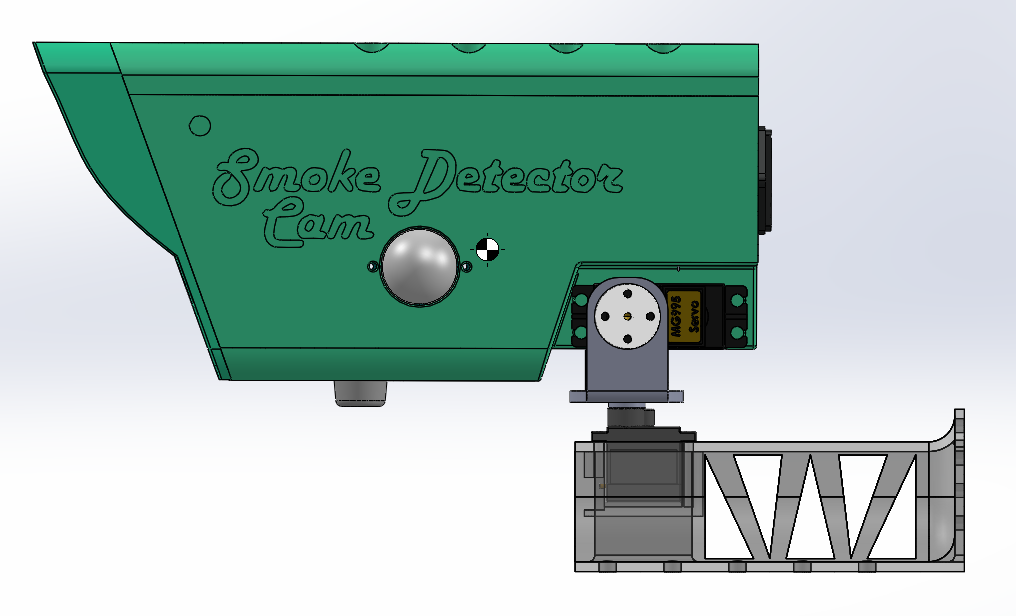
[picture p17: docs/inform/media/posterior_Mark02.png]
      
    \end{adjustbox}
    \caption{\label{fig:posterior_Mark02}Vista Posterior de la versión Mark II.}
    \end{figure}

    En la Figura \ref{fig:posterior_Mark02} se aprecia que la ubicación de los servomotores se mantienen pero el soporte de los mismos se cambio. El primer cambio fue el soporte para instalar la cámara a la pared, de forma que se podría colocar y soportar el peso de la cámara. Además, de una pieza para que la cámara pueda rotar con facilidad sobre el eje Y.

    Cabe mencionar que en todas estas iteraciones se mantuvo la ubicación del ventilador para la refrigeración de los componentes electrónicos.

%\needspace{3cm}
\subsection{Mark III}
    En el Mark III se desarrolló un cambio total del sistema, forma y mecanismo de funcionamiento de la cámara tras aplicar e método de diseño y análisis de los cinco pasos.
    Se puede apreciar en la Figura~\ref{fig:Mark03} que el modelo obtenido es mucho mas parecido a una cámara moderna que en las versiones anteriores.
    
    \begin{figure}[H]
    \centering
    \begin{adjustbox}{width=\linewidth}
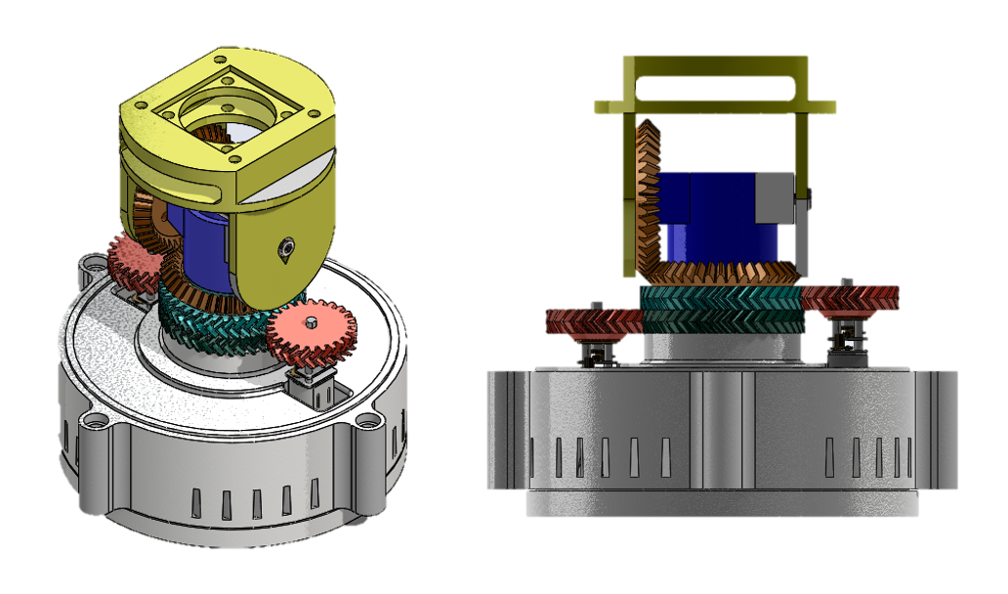
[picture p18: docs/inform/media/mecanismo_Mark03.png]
      
    \end{adjustbox}
    \caption{\label{fig:mecanismo_Mark03} Mecanismo de la versión Mark III.}
    \end{figure}

    En la Figura \ref{fig:mecanismo_Mark03} se puede apreciar el mecanismo que queda claro en el cuadro \ref{tab:combinacion_3}, que es el Tren de Engranes Diferencial, usando motores DC y cada uno con una velocidad angular de 100rpm, de esta forma se tiene un movimiento de 600°/seg.
    La relacion de los engranes es que lo de los laterales (color rojo) tienen 24 dientes y los dos engranes grandes (los equivalente a color verde) tienen 40 dientes.

    \begin{figure}[H]
    \centering
    \begin{adjustbox}{width=\linewidth/3}
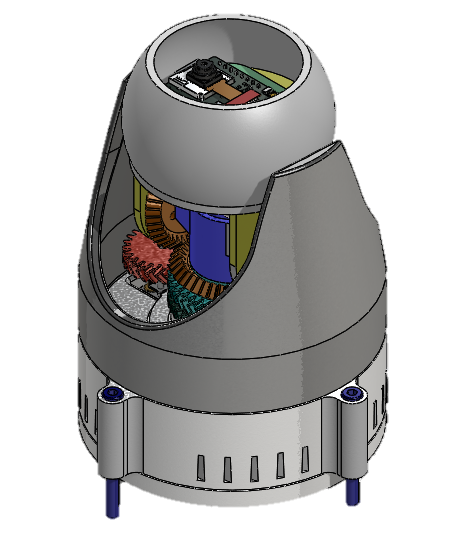
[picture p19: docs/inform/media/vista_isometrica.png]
      
    \end{adjustbox}
    \caption{\label{fig:Mark03} Vista Isometrica de la versión Mark III.}
    \end{figure}

    En la Figura \ref{fig:Mark03}, se presenta una visión detallada del mecanismo de la cámara dentro de su elegante carcasa. Se destaca especialmente el movimiento preciso que ejecuta este mecanismo para posicionar la cámara en el ángulo exacto necesario para capturar la imagen de la persona que está fumando. Es importante señalar que todo el sistema de alimentación y placa de potencia se ubican en la parte inferior de la estructura. En la parte superior, justo debajo de la ESP32-CAM, se encuentra el ventilador, mientras que las rejillas en la parte inferior permiten la refrigeración de la placa de potencia. El flujo del aire de refrigeración para este prototipo se puede apreciar en la Figura~\ref{fig:flujoDeAire}. Seria este mismo canal común dentro del cual se tienen que ordenar los cables y conexiones de los dispositivos electrónicos del sistema.

    \begin{figure}[H]
    \centering
    \begin{adjustbox}{width=\linewidth}
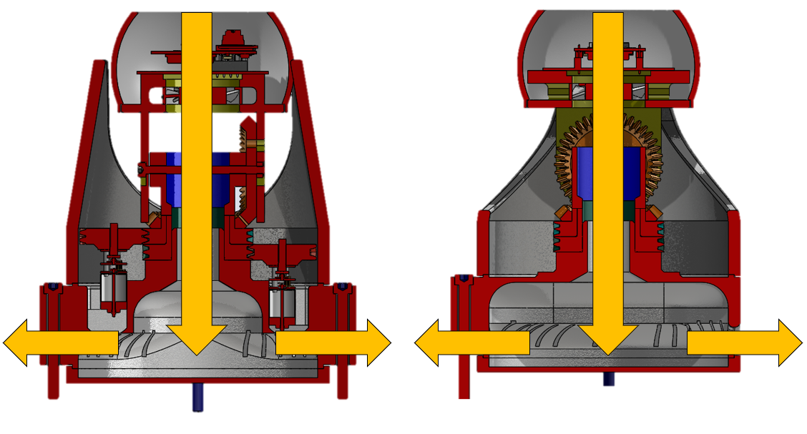
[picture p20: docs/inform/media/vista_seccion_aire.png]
    
    \end{adjustbox}
    \caption{\label{fig:flujoDeAire} Vista de sección de la cámara en la que se puede apreciar el flujo de aire empujado por el ventilador planteado mediante las fechas amarillas.}
    \end{figure}

    \subsubsection{Base de la Cámara}
    La base de la cámara se diseñó con un enfoque primordial en el mecanismo que debía ubicarse sobre ella, así como en los componentes que debían ser alojados en su interior. Estos componentes incluían la unidad de potencia, módulos de posible expansión, conductos de refrigeración, baterías, el método de sujeción, la facilidad de impresión 3D y, por último, la estética del producto.

    A partir del complejo mecanismo de transmisión de movimiento, compuesto por una variedad de engranajes, se logró desarrollar la forma del encapsulado de manera orgánica. Se creó una base circular hueca diseñada para albergar los componentes de potencia en su interior, con orificios estratégicos destinados a sujetar los motores DC mediante un apriete preciso. Además se trató de mantener las secciones sobresalientes a mas de 45 grados tal y como propone \cite{Redwood_2017} a fin de no necesitar soportes para la impresión de la misma o en su defecto de mantener los puentes con un longitud igual o inferior a un centímetro.
    
    En cuanto a la sujeción, se planteó la utilización de tres tornillos, y la posición del cuarto tornillo fue sustituida por un agujero que permitía el paso de los cables de alimentación, manteniendo así la integridad de la estética del producto.
    
    \subsubsection{Engranes Helicoidales}
    Los engranes helicoidales destacan como una elección sobresaliente en la concepción de mecanismos para sistemas de impresión 3D ya que su mayor complejidad geométrica no implica un mayor costo de producción o necesidad de remover soportes. Su característica más distintiva radica en la inclinación helicoidal de los dientes en lugar de ser perpendiculares al eje de rotación. Esta inclinación suave desempeña un papel fundamental en la reducción de ruido y vibraciones.
    Además de la reducción de ruido y las ventajas en la capacidad de carga, es esencial entender cómo se llevó a cabo la reducción de velocidad mediante el uso de engranes en tu sistema. En tu caso, tienes un motor con una velocidad de entrada de 100 RPM, y en su eje hay un engrane con 24 dientes conectado a otro con 40 dientes. Para calcular la reducción de velocidad que este conjunto de engranes proporciona se utiliza la siguiente fórmula:

    \begin{equation}
    \text{Reducción de velocidad} = \frac{\text{Número de dientes del engrane conductor}}{\text{Número de dientes del engrane conducido}}
    \end{equation}
    
    En este caso, el engrane conductor es el que tiene 24 dientes, y el engrane conducido es el de 40 dientes, por lo que la reducción de velocidad es:
    
    \begin{equation*}
    \text{Reducción de velocidad} = \frac{24}{40} = 0.6
    \end{equation*}
    
    Esto significa que el sistema de engranes reduce la velocidad del motor en un 60\%.
    La elección del módulo y el número de dientes en los engranes fue un proceso iterativo que involucró la optimización tanto de la estética como del tamaño del sistema, al mismo tiempo que se buscaba reducir la velocidad de los motores.
    
    \subsubsection{Engranes Cónicos}
    Los engranes cónicos permiten la transferencia de movimiento rotacional de un plano a otro con un ángulo de desviación, esencial para mantener una transmisión de potencia eficiente en el mecanismo diferencial. En este caso se colocaron a 45 grados para poder mover la cámara en los ejes planteados, mismos que son normales el uno del otro.

    \subsubsection{Torreta}
    La torreta se posiciona como una pieza central del mecanismo, permite posicionar el eje del brazo, así como sincronizar el movimiento de uno de los engranes helicoidales con el movimiento sobre el plano de planta que debe realizar la cámara. Adicionalmente, al ser hueco funciona como conducto de aire de refrigeración.
    
    \subsubsection{Brazo}
    El brazo del mecanismo permite conectar el efector final al mecanismo por medio de pernos y ejes que lo alinean al mismo. En el Mark III se colocaron la placa de control en donde se sitúa la cámara así como el ventilador al final del brazo. Más aun, se tomó en cuenta la posición de impresión del brazo al momento de diseñar las sujeciones laterales. Estos agujeros presentan formas de gota de agua, esto debido a que se agrega un ángulo por la parte superior de los orificios para evitar el uso de soportes al momento de impresión. En este caso la gota tiene un ángulo de sesenta grados lo que permite impresión sin problemas en materiales como el ABS o el PLA sin problemas. El ángulo se puede disminuir hasta cuarenta  cinco grados en caso de limitarse utilizar PLA.
    Se diseñaron dos modelos: Uno con frente recto y otro con frente redondeado.
    
    \subsubsection{Carcasa}
    Finalmente la carcasa exterior tiene la función de resguardar el mecanismo en su interior sin perjudicar el movimiento del mecanismo. Tratando de imitar las cámaras modernas, tales como la descrita en la Figura~\ref{fig:Imou} se diseñó uno compuesto por una carcasa exterior con conjunto con un esferoide posicionado mediante apriete alrededor de la cámara conectada en el brazo. 

    \needspace{6cm}
    \subsection{Mark IV}

    \begin{figure}[H]
    \centering
    \begin{adjustbox}{width=0.7\linewidth}
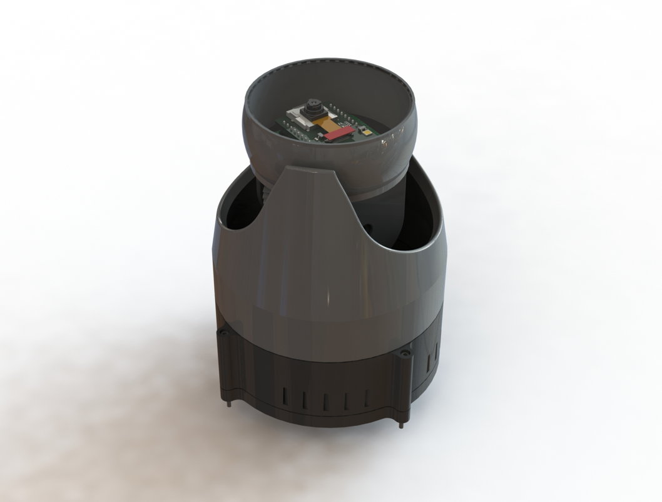
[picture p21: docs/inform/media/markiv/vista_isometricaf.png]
      
    \end{adjustbox}
    \caption{\label{fig:Mark04} Vista Isometrica Renderizada de la versión Mark IV.}
    \end{figure}

    En la versión Mark IV se modificó la posición del ventilador en el ensamble. Pasando de estar montado en el brazo junto a la sección de control a estar montado en la torreta por encima de la sección de potencia. Respetando de igual manera el flujo de aire explicado en la Figura~\ref{fig:flujoDeAire}.
    
    \subsubsection{Torreta}

    \begin{figure}[H]
    \centering
    \begin{adjustbox}{width=0.7\linewidth}
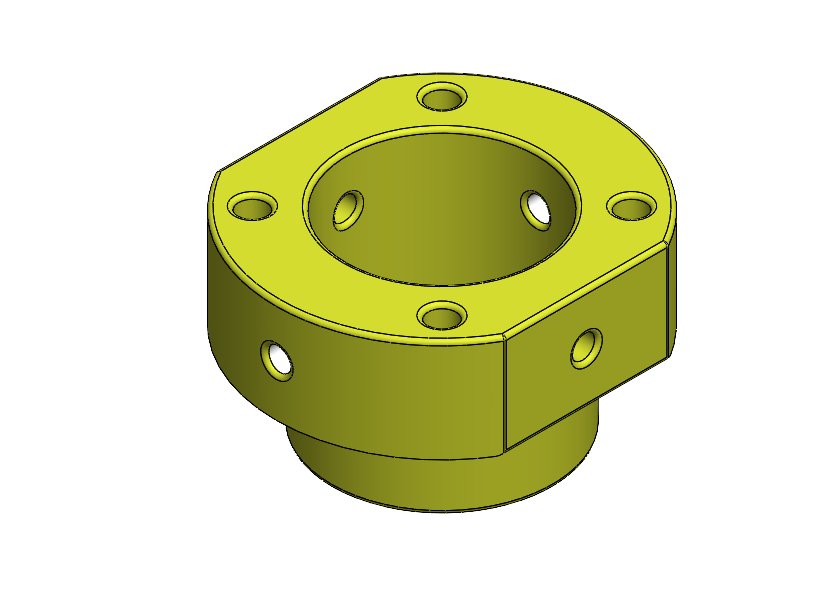
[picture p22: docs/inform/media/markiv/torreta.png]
      
    \end{adjustbox}
    \caption{\label{fig:torretaMarkIV} Vista Isometrica de la Torreta modificada en la versión Mark IV.}
    \end{figure}
    
    La Figura~\ref{fig:torretaMarkIV} muestra los cambios realizados en la Torreta para permitir el montaje del ventilador por encima de la misma de manera que la sección de potencia cuente siempre con un flujo constante de aire en su interior.
    
    \subsubsection{Brazo}

    \begin{figure}[H]
    \centering
    \begin{adjustbox}{width=0.7\linewidth}
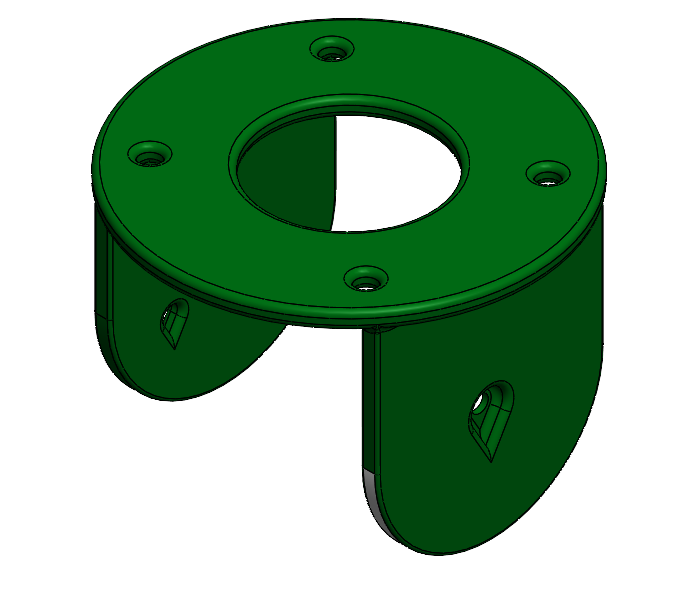
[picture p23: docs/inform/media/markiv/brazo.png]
      
    \end{adjustbox}
    \caption{\label{fig:brazoMarkIV} Vista Isometrica del Brazo modificado en la versión Mark IV.}
    \end{figure}

     La Figura~\ref{fig:brazoMarkIV} permite apreciar que al no tener una abertura para colocar el ventilador el diseño del brazo que sostiene al circuito de control se ve simplificado, permitiendo su impresión en maquinas FDM sin soportes.

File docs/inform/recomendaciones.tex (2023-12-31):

En el proceso de desarrollo del sistema "Smoke Detector Cam" para la detección temprana de humo y fuego en ambientes cerrados, se han tomado decisiones clave, como la elección de motores DC, el uso de un mecanismo de tren de engranajes diferencial, baterías de Li-Ion, abrazaderas para la gestión de cables y un sistema de refrigeración con un ventilador ubicado sobre las placas electrónicas. Sin embargo, es esencial considerar ciertos aspectos para garantizar el éxito y la eficacia del proyecto.

En primer lugar, la pieza o sección que requiere mayor consideración es el diseño de la carcasa. El diseño actual no permite proteger al mecanismo en todos su circunferencia de partículas de polvo o humo así como también depende en gran medida del ajuste por apriete para mantenerse en posición. En su defecto de pegamentos, restringiendo los grados de libertad de la cámara en este caso.

En cuanto al mecanismo de tren de engranajes diferencial, se tiene pensado realizar pruebas rigurosas para asegurar su robustez y eficiencia, garantizando su capacidad de funcionar en condiciones variables de humedad y temperatura.

Queda pendiente además de las abrazaderas para cables, la implementación de conectores o interfaces que faciliten el ensamblaje y el mantenimiento del sistema.

Por otro lado, las pruebas de flujo de aire y simulaciones de temperatura son necesarias para garantizar que el ventilador sea capaz de mantener las temperaturas dentro de rangos seguros. La instalación de sensores de temperatura para un monitorio activo puede ser una medida adicional para mantener un control preciso de la temperatura.

Más aun, se debe revisar cada una de las piezas diseñadas para optimizarlas mismas para su manufactura mediante impresión 3D. Por ejemplo, es necesario tomar en cuenta que no se recomiendan agujeros de diámetro menor o igual a dos milímetros y mas aun, independientemente del diámetro si no se toman consideraciones para permitir la flexibilidad de los mismos resulta difícil asegurar el ajuste por apriete en la producción en masa de piezas impresas.

Finalmente, las pruebas y validaciones en diferentes entornos y condiciones son esenciales para garantizar el rendimiento del "Smoke Detector Cam". Además, considerar la implementación de un sistema de registro de datos para recopilar información sobre el funcionamiento del dispositivo puede ser valioso para análisis posteriores y mejoras en el diseño.

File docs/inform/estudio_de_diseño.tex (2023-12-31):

\begin{table}[!ht]
\begin{adjustbox}{width=\columnwidth,center}
\centering
\small
    \begin{tabularx}{\textwidth}{|l|X|l|l|l|l|l|l|l|l|l|}
    \hline
        ~ & Objet. & Act. & Inicial & Esc1 & Esc2 & Esc3 & Esc4 & Esc5 & Esc6\\ \hline
        Diám(mm) & ~ & 5 & 2 & 2.50 & 3 & 3.50 & 4 & 4.50 & 5 \\ \hline
        Tensión($N/m^2$) & $10^7$ & 3430 & 8 & 8 & 7 & 8 & 1 & 7 & 9\\ \hline
        Masa($g$) & Min& 167.2 & 163.4 & 164.0 & 164.6 & 165.3 & 165.9 & 166.5 & 167.2\\ \hline
    \end{tabularx}
    \end{adjustbox}
    \label{tab:estudioDisenoBase}
    \caption{Resultados de Estudio de Diseño para la Base de la Cámara. Se puede notar en verde los puntos de mayor tensión, en rojo la gravedad y en rosado la carga distribuida de la cámara en la estructura.}
\end{table}

En base al análisis previo se realizó una simulación de carga estática especifica de la base de la cámara a fin de optimizar el diámetro de los pernos que sostienen la estructura como se aprecia en la Figura~\ref{fig:simBase}.
El Cuadro~\ref{tab:estudioDisenoBase} expone los resultados obtenidos en el estudio. En el mismo se determinó que el diámetro óptimo es aquel que utiliza el mínimo permitido por el método de manufactura, es decir, 2 mm.

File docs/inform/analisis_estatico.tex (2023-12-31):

    Se desarrolló el análisis estático de la cámara MARK III para fuerzas de gravedad cuando la misma se encuentra montada en diferentes orientaciones, sea de lado o de cabeza. 
    En primer lugar, para desarrollar el análisis estático fue necesario simplificar el modelo del mecanismo de las secciones que no son relevantes para el análisis, como los dientes de los engranes por ejemplo como se aprecia en la Figura \ref{fig:configuracionSimplificada}.
    
    \begin{figure}[H]
    \centering
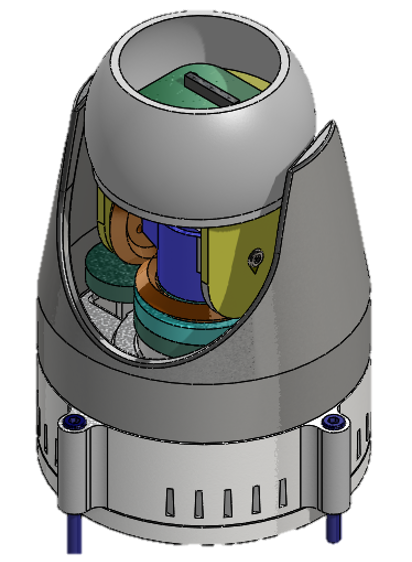
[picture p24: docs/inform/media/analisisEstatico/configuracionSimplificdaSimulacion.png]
    \begin{adjustbox}{width=\linewidth/2} 
    \end{adjustbox}
    \caption{\label{fig:configuracionSimplificada}Configuración simplificada del modelo optimizada para simulación.}
    \end{figure} 
    
    Se tomó en cuenta que las cargas mas importantes del sistema son los motores, con 9.5 gramos cada uno, la placa de la cámara de 10 gramos y el conjunto de potencia con un promedio de 250 gramos y se representó estas cargas mediante fuerzas para simplificar el análisis. En la Figura \ref{fig:deformaciones_unitarias} se pueden observar tres simulaciones, una para cada orientación para las que la cámara esta diseñada a montarse. Se puede notar en la Figura que las deformaciones se encuentran dentro del limite elástico del plástico seleccionado, en este caso ABS. 
    
    \begin{figure}[H]
    \centering
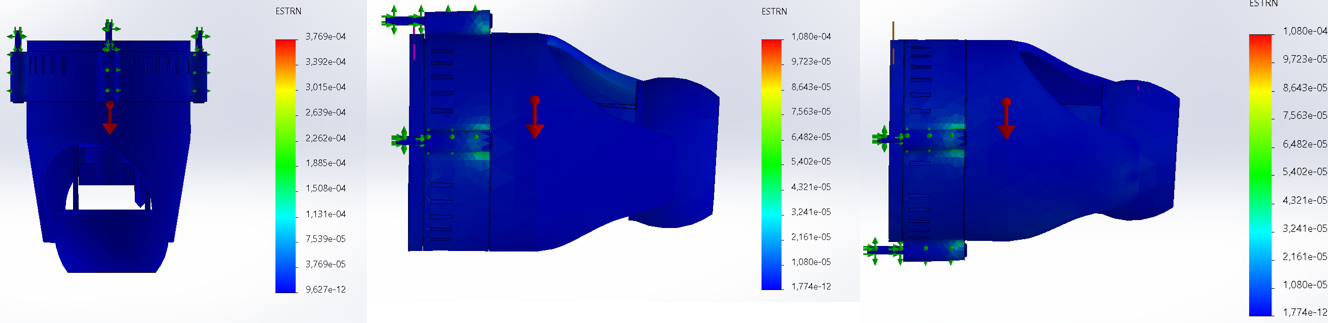
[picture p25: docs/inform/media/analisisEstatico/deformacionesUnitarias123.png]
    \begin{adjustbox}{width=\linewidth} 
    \end{adjustbox}
    \caption{\label{fig:deformaciones_unitarias}Estudio de Deformaciones Unitarias del MARK III ante carga de la gravedad en diferentes orientaciones.}
    \end{figure} 

    Por otro lado, la Figura~\ref{fig:deformaciones_unitarias} muestra los desplazamientos, lo mas notable es que el mecanismo de la cámara tiende a desplazarse un promedio de 0.007 mm hacia la dirección de la gravedad cuando la cámara se coloca de lado.

    \begin{figure}[H]
    \centering
    \begin{adjustbox}{width=\linewidth} 
    \end{adjustbox}
    \caption{\label{fig:analisisDesplazamientos}Estudio de Desplazamientos del MARK III ante carga de la gravedad en diferentes orientaciones.}
    \end{figure} 

    La Figura~\ref{fig:analisisTensiones} permite apreciar el análisis de tensiones. Nada que destacar del análisis de tensiones.

    \begin{figure}[H]
    \centering
    \begin{adjustbox}{width=\linewidth} 
    \end{adjustbox}
    \caption{\label{fig:analisisTensiones}Estudio de Tensiones del MARK III ante carga de la gravedad en diferentes orientaciones.}
    \end{figure} 

    \begin{figure}[H]
    \centering
    \begin{adjustbox}{width=\linewidth} 
    \end{adjustbox}
    \caption{\label{fig:simBase} Análisis Estático de la Base de la Cámara.}
    \end{figure} 
    
    Finalmente en la Figura~\ref{fig:simBase} se simuló la carga de la carcasa, componentes y conjunto electrónico en la carcasa, puesto que es la base de donde se sostiene la misma. Se colocó la carga distribuida en los soportes y superficies superiores de la base mientras se fijaba los soportes para pernos.

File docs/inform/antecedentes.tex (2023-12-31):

El tabaquismo es una epidemia mundial con graves consecuencias para la salud, la sociedad y la economía. En Bolivia, aproximadamente el 21,9\% de los hombres y alrededor del 9\% de las mujeres consumen tabaco diariamente(\cite{BoliviaTobaccoControlLaw}). Además, un preocupante 46,6\% de los jóvenes están expuestos al humo de tabaco ajeno, y cada año más de 4.600 bolivianos y bolivianas pierden la vida debido a enfermedades relacionadas con el consumo de tabaco.

Para abordar esta preocupante situación, se promulgó una importante ley de control del tabaco en Bolivia. Misma que estableció que todos los espacios cerrados de acceso público y lugares de trabajo deben ser 100\% libres de humo de tabaco, protegiendo así a toda la población de los riesgos asociados a la exposición al humo de segunda mano. Según lo reportado por la Organización Mundial de la Salud (OMS) se estima que alrededor de 8 millones de personas mueren cada año debido al tabaquismo, de las cuales 7 millones de muertes son atribuidas al consumo directo de tabaco y 1 millón de muertes son causadas por el humo de tabaco ajeno.

Además de los impactos en la salud, el tabaquismo también genera una significativa carga económica, con la OMS estimando que la economía mundial tiene que soportar más de USD 500 mil millones cada año debido a problemas relacionados con el tabaquismo.

La vigilancia basada en inteligencia artificial de las áreas de no fumar para detectar fumadores como posibles infractores es esencial(\cite{Khan2022b}). Al tener una solución automatizada y precisa, las autoridades pueden aplicar medidas correctivas oportunas y fomentar el cumplimiento de las regulaciones, mejorando así la calidad de vida y el bienestar general en el contexto de ciudades inteligentes.
Esta solución puede contribuir significativamente al monitoreo y prevención del consumo de tabaco en espacios donde está prohibido fumar.

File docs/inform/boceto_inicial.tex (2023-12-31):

\begin{figure}[H]
\centering

\caption{\label{fig:concept_art}Arte conceptual del producto.}
\end{figure}

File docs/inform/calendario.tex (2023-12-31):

\calwidth=15.5cm

% Few useful commands (our classes always meet either on Monday and Wednesday 
% or on Tuesday and Thursday)

\newcommand{\MWClass}{%
\calday[Monday]{\classday}
\calday[Tuesday]{\classday}
\calday[Wednesday]{\classday} 
\calday[Thursday]{\classday}  
\calday[Friday]{\classday}
\skipday\skipday % weekend (no class)
}

\newcommand{\TRClass}{%
\calday[Monday]{\classday}
\calday[Tuesday]{\classday} 
\calday[Wednesday]{\classday}
\calday[Thursday]{\classday} 
\calday[Friday]{\classday} % 
\skipday\skipday % weekend (no class)
}

\newcommand{\Holiday}[2]{%
\options{#1}{\noclassday}
\caltext{#1}{#2}
}

%\paragraph*{Calendario del Proyecto Smoke Detector Cam:}
\begin{center}
\begin{calendar}{08/28/2023}{15} % Semester starts on 1/11/2010 and last for 18

% weeks, including finals week
\setlength{\calboxdepth}{.25in}
\TRClass
% schedule

% Semana 5
\caltexton{0}{}

% Semana 6
\caltexton{6}{}

% Semana 7
\caltexton{5}{Presentación de propuestas de proyecto\cellcolor{green}}
\caltexton{7}{Objetivo 1.1}
\caltexton{10}{Objetivo 1.2}

% Semana 8
\caltexton{12}{}
\caltexton{15}{Metodo de los 5 pasos\cellcolor{green}}

% Semana 9 Examenes
\caltexton{16}{\cellcolor{red}}
\caltextnext{Objetivo 2.1\cellcolor{red}}
\caltextnext{\cellcolor{red}}
\caltextnext{\cellcolor{red}}
\caltextnext{\cellcolor{red}}
\caltexton{20}{Objetivo 1.4\cellcolor{red}}

% Semana 10 Examenes
\caltexton{21}{\cellcolor{red}}
\caltextnext{Objetivo 1.5\cellcolor{red}}
\caltextnext{\cellcolor{red}}
\caltextnext{\cellcolor{red}}
\caltextnext{\cellcolor{red}}

% Semana 11 Examenes
\caltexton{26}{\cellcolor{red}}
\caltextnext{\cellcolor{red}}
\caltextnext{\cellcolor{red}}
\caltextnext{\cellcolor{red}}
\caltextnext{\cellcolor{red}}

% Semana 12 Examenes
\caltexton{31}{\cellcolor{red}}
\caltextnext{\cellcolor{red}}
\caltextnext{\cellcolor{red}}
\caltextnext{\cellcolor{red}}
\caltextnext{\cellcolor{red}}

% Semana 13
\caltexton{36}{Objetivo 2.1\\Objetivo 2.2}

% Semana 14
\caltexton{41}{Objetivo 2.3}
\caltexton{44}{}

% Semana 15
\caltexton{47}{Objetivo 2.4}
\caltexton{49}{Proyecto Finalizado\cellcolor{green}}

% Semana 16 Examenes
\caltexton{50}{\cellcolor{red}}
\caltextnext{Objetivo 3.1\cellcolor{red}}
\caltextnext{\cellcolor{red}}
\caltextnext{\cellcolor{red}}
\caltextnext{\cellcolor{red}}

% Semana 17 Examenes
\caltexton{55}{\cellcolor{red}}
\caltextnext{Objetivo 3.2\cellcolor{red}}
\caltextnext{\cellcolor{red}}
\caltextnext{\cellcolor{red}}
\caltextnext{\cellcolor{red}}

% Semana 18
\caltexton{60}{}
\caltexton{61}{Objetivo 3.3}

% Semana 19 Finales
\caltexton{65}{\cellcolor{red}}
\caltextnext{\cellcolor{red}}
\caltextnext{\cellcolor{red}}
\caltextnext{\cellcolor{red}}
\caltextnext{\cellcolor{red}}

% Semana 20 Finales
\caltexton{70}{\cellcolor{red}}
\caltextnext{\cellcolor{red}}
\caltextnext{\cellcolor{red}}
\caltextnext{\cellcolor{red}}
\caltextnext{\cellcolor{red}}
\caltext{12/8/2023}{Ultimo día del semestre}

% Feriados
\Holiday{1/1/2023}{Año Nuevo (domingo) \cellcolor{orange}}
\Holiday{1/22/2023}{Estado plurinacional (domingo, festivo especial) \cellcolor{orange}}
\Holiday{2/20/2023}{Carnaval (lunes) \cellcolor{orange}}
\Holiday{2/21/2023}{Carnaval (martes) \cellcolor{orange}}
\Holiday{4/6/2023}{Semana Santa (jueves) \cellcolor{orange}}
\Holiday{4/7/2023}{Semana Santa (viernes) \cellcolor{orange}}
\Holiday{5/1/2023}{Día del Trabajador \cellcolor{orange}}
\Holiday{6/8/2023}{Corpus Christi (jueves) \cellcolor{orange}}
\Holiday{6/21/2023}{Año Nuevo aymara o andino \cellcolor{orange}}
\Holiday{8/7/2023}{Día de la Independencia \cellcolor{orange}}
\Holiday{11/2/2023}{Día de los Difuntos \cellcolor{orange}}
\Holiday{12/25/2023}{Navidad (lunes) \cellcolor{orange}}

\options{4/26/2023}{\noclassday} % finals week
\options{4/27/2023}{\noclassday} % finals week
\options{4/28/2023}{\noclassday} % finals week
\options{4/29/2023}{\noclassday} % finals week
\options{4/30/2023}{\noclassday} % finals week
\caltext{4/27/2023}{\textbf{Final Exam}}
\end{calendar}
\end{center}

\begin{minipage}{\linewidth}
    \subsection*{Objetivo 1: Diseñar el sistema electrónico de la cámara inteligente "Smoke Detector Cam"}
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

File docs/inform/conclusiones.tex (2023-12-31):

En conclusión, el proyecto de desarrollo del sistema embebido 'Smoke Detector Cam', concebido para detectar tempranamente humo y fuego en ambientes cerrados, fue delineado eficazmente a través de una serie de objetivos específicos. Desde su primera versión, enfocada en formalizar la estructura y la mecánica de movimiento de la cámara, hasta las iteraciones posteriores, el proyecto experimentó notables evoluciones.
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

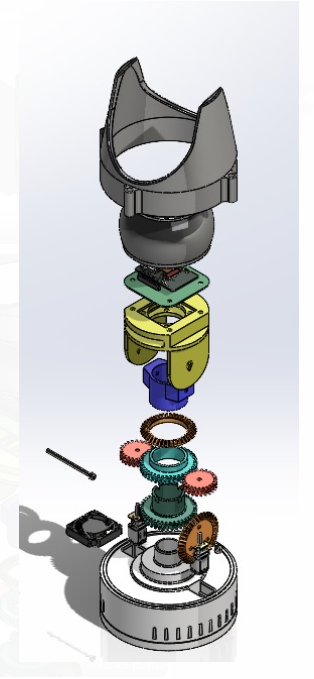
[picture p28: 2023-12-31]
docs/inform/media/esplosion_Mark03.png

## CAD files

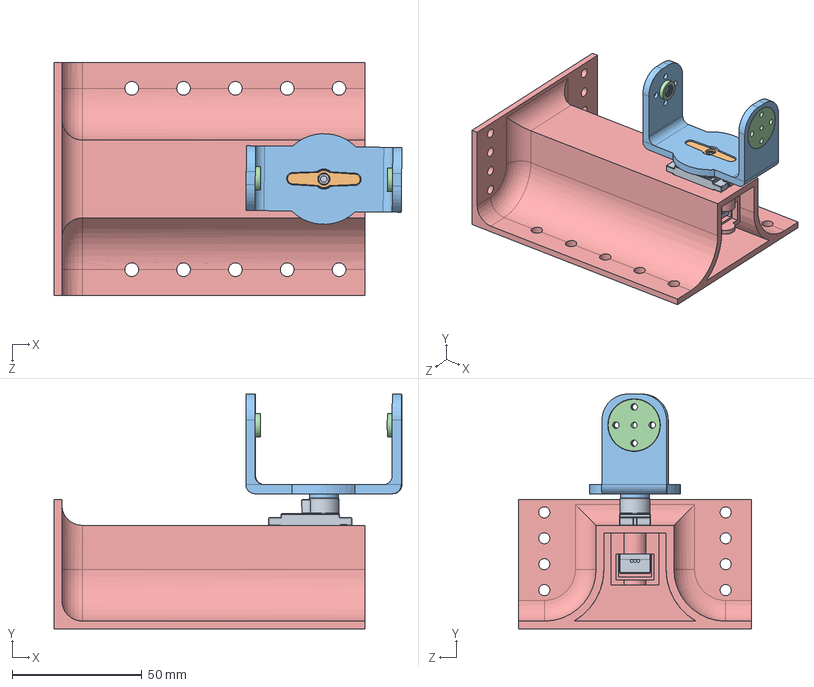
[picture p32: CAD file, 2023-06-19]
cad/mark_02/components/CameraHolder.SLDASM
134.3 x 90.7 x 90.0 mm
MG90S
Microservo horn
cameraHolder
MG955 horn x 2
Soporte_motor

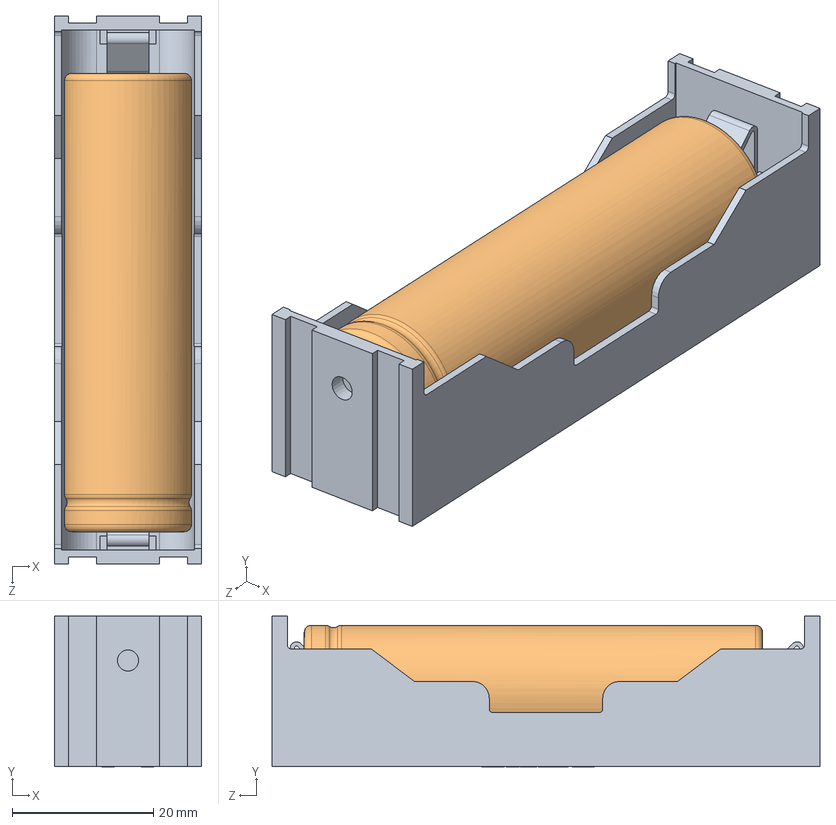
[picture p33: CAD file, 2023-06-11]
cad/mark_02/components/battery_assembly.SLDASM
20.9 x 21.4 x 77.7 mm
Li-Ion_Cell_Holder_BH_18650_A
АКБ 18650

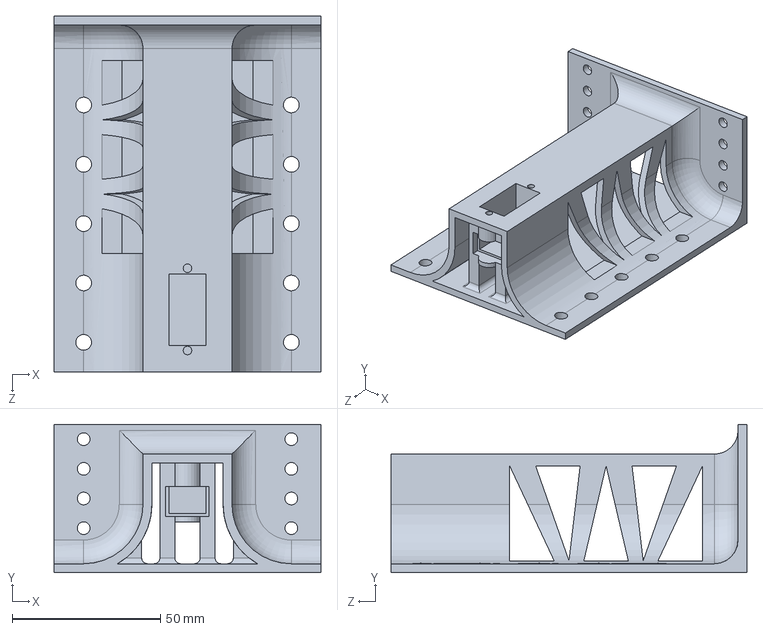
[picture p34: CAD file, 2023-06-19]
cad/mark_02/enclosures/Soporte_motor.SLDPRT
90.0 x 50.0 x 120.0 mm

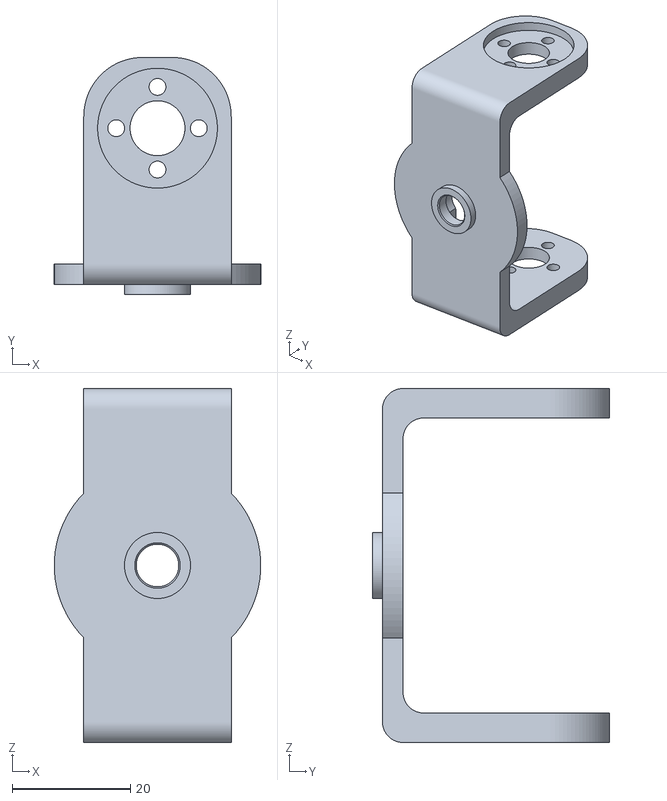
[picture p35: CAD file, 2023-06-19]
cad/mark_02/printables/cameraHolder.STL
35.0 x 40.2 x 60.0

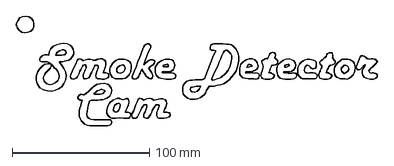
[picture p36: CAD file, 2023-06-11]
cad/mark_02/schematics/logo.dxf
263.1 x 79.8 mm

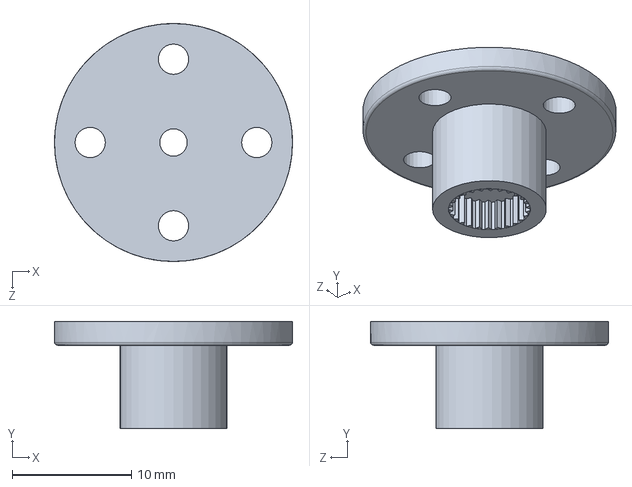
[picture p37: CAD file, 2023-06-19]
cad/mark_02/components/MG955 horn.SLDPRT
20.0 x 9.00 x 20.0 mm

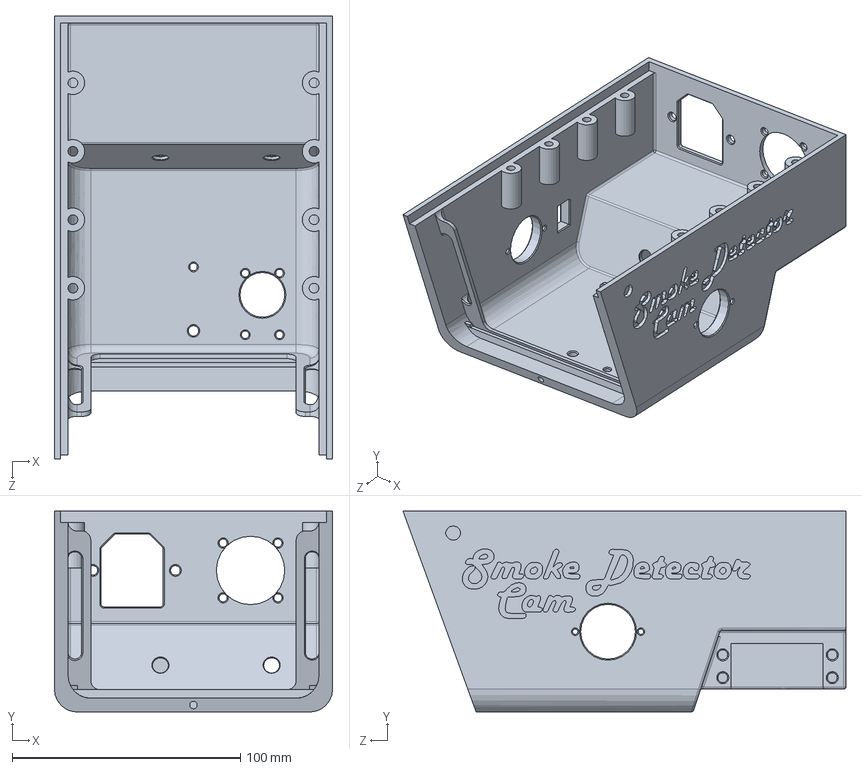
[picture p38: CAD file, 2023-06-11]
cad/mark_02/enclosures/body.SLDPRT
122.0 x 88.0 x 194.2 mm

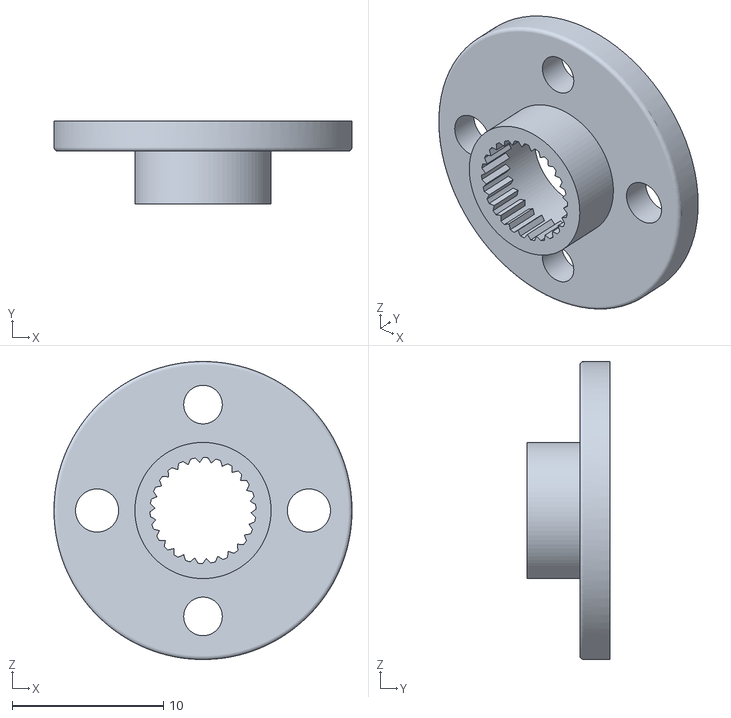
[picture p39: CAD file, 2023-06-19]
cad/mark_02/printables/MG955 horn.STL
19.7 x 5.50 x 19.7

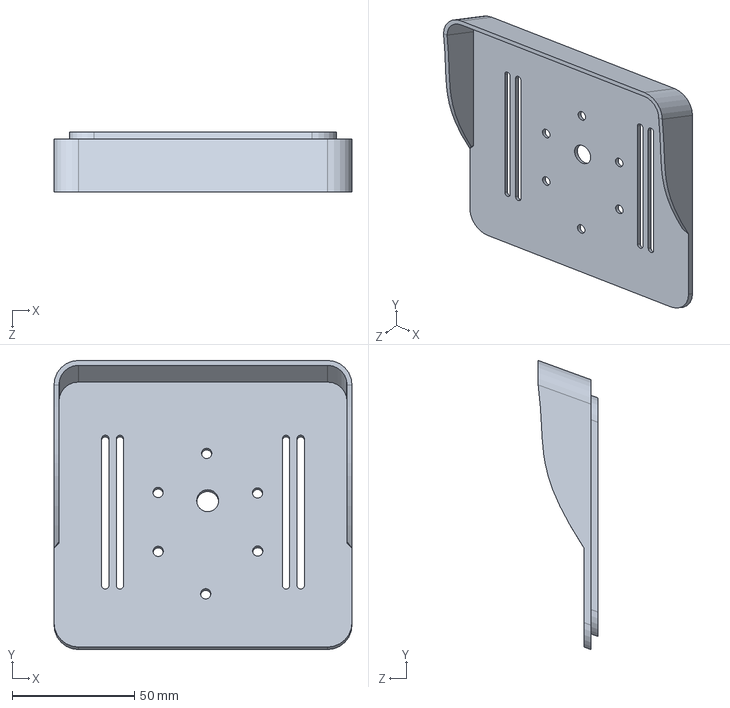
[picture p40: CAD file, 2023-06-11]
cad/mark_02/enclosures/front.SLDPRT
122.0 x 118.4 x 24.4 mm

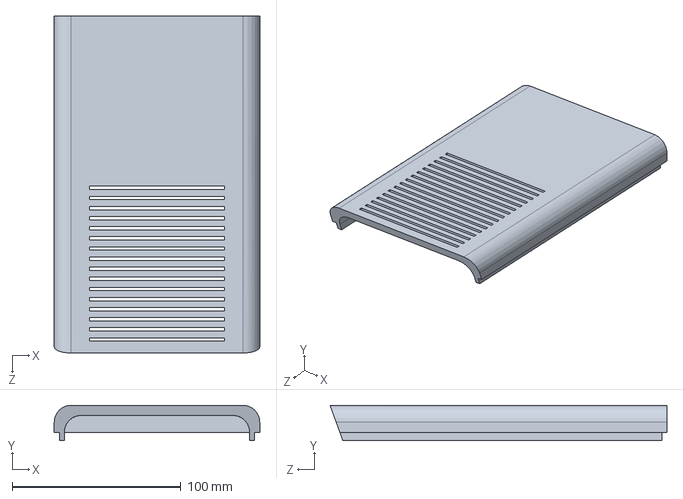
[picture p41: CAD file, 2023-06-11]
cad/mark_02/enclosures/top.SLDPRT
122.0 x 21.0 x 200.0 mm

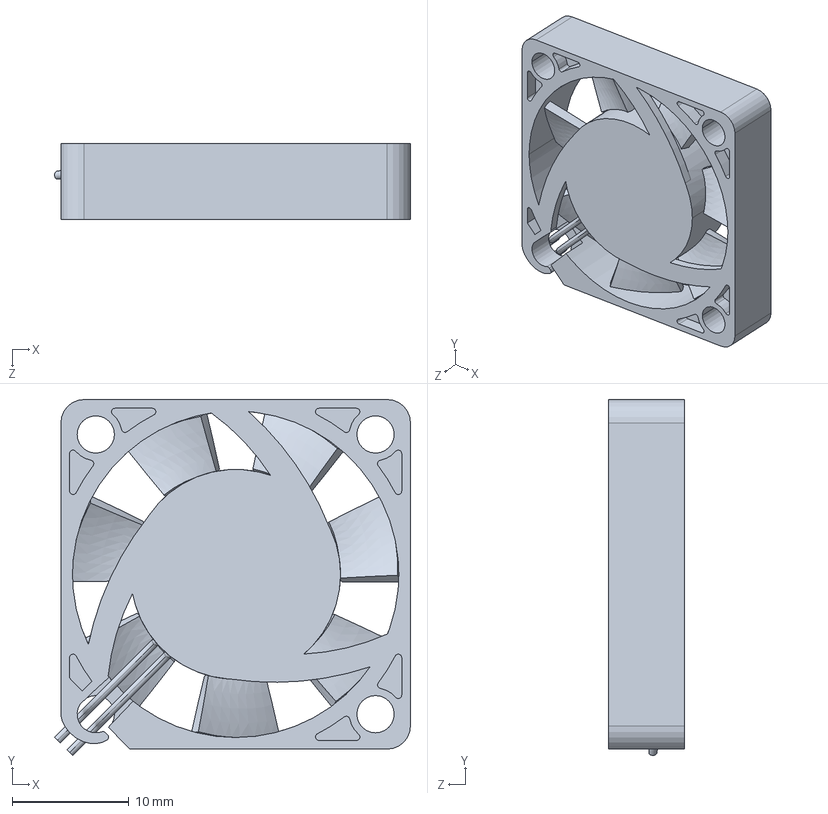
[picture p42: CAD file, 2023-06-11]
cad/mark_02/components/DC_FAN_30x30x6.SLDPRT
30.5 x 30.5 x 6.50 mm

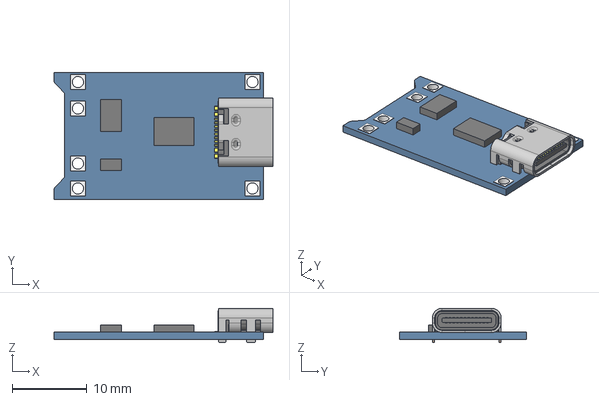
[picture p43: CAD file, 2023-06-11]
cad/mark_02/components/TP4056 charge module with protection.stp
29.3 x 17.0 x 4.60 mm

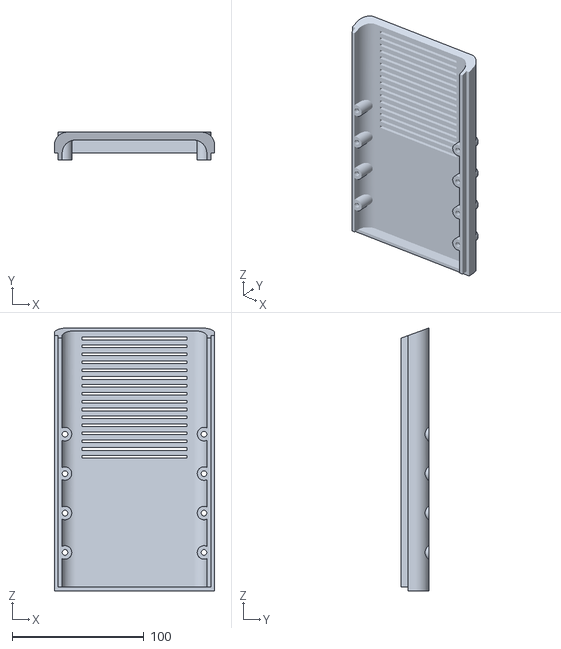
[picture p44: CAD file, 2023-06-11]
cad/mark_02/printables/top.STL
122.0 x 21.0 x 200.0

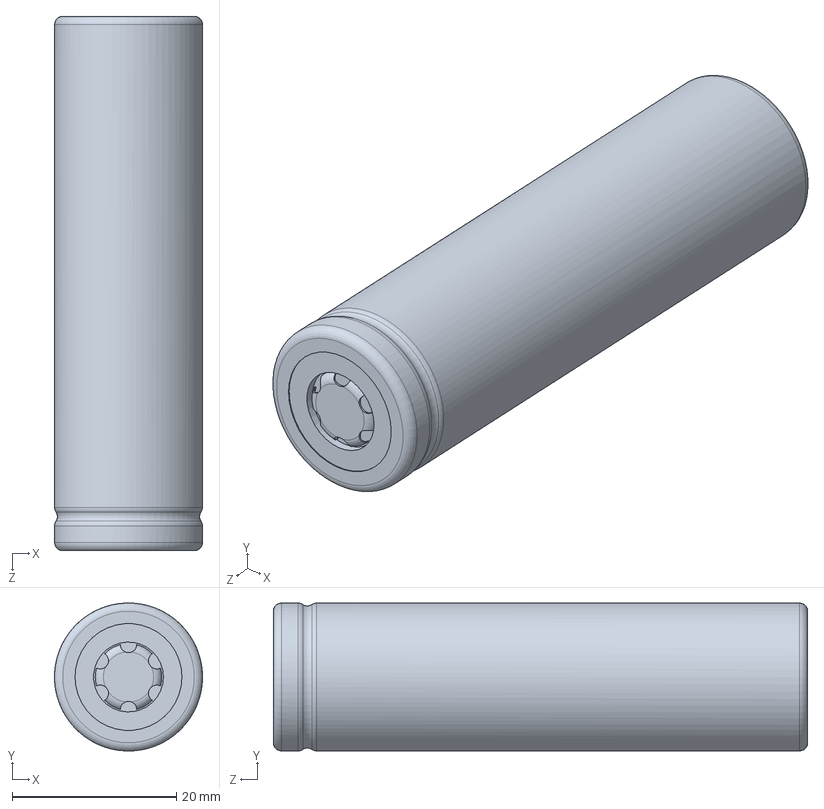
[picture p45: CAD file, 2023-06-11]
cad/mark_02/components/АКБ 18650.SLDPRT
18.0 x 18.0 x 65.0 mm

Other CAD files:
cad/mark_02/components/MG955 horn_sopport.SLDPRT
cad/mark_02/printables/MG955_horn_sopport.SLDPRT
cad/mark_02/printables/Soporte_motor.STL
cad/mark_02/printables/body.STL
cad/mark_00/Ensamblaje1.SLDASM
cad/mark_00/Esamblaje camara.SLDASM
cad/mark_00/enclosures/Base motor.SLDPRT
cad/mark_00/enclosures/Tapa Trasera.SLDPRT
cad/mark_00/enclosures/cuerpo camara.SLDPRT
cad/mark_00/enclosures/pieza de rotacion.SLDPRT
cad/mark_00/enclosures/tapa delantera.SLDPRT
cad/mark_00/enclosures/tapa superior.SLDPRT
cad/mark_01/Esamblaje camara.SLDASM
cad/mark_01/components/DC_FAN_30x30x6.stp
cad/mark_01/components/Ensamblaje1.SLDASM
cad/mark_01/components/MG995.STEP
cad/mark_01/components/MG995.step.SLDPRT
cad/mark_01/components/MQ-2.step
cad/mark_01/components/MQ135_sensor.step
cad/mark_01/components/Switch.STEP
cad/mark_01/enclosures/Base motor.SLDPRT
cad/mark_01/enclosures/Tapa Trasera.SLDPRT
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

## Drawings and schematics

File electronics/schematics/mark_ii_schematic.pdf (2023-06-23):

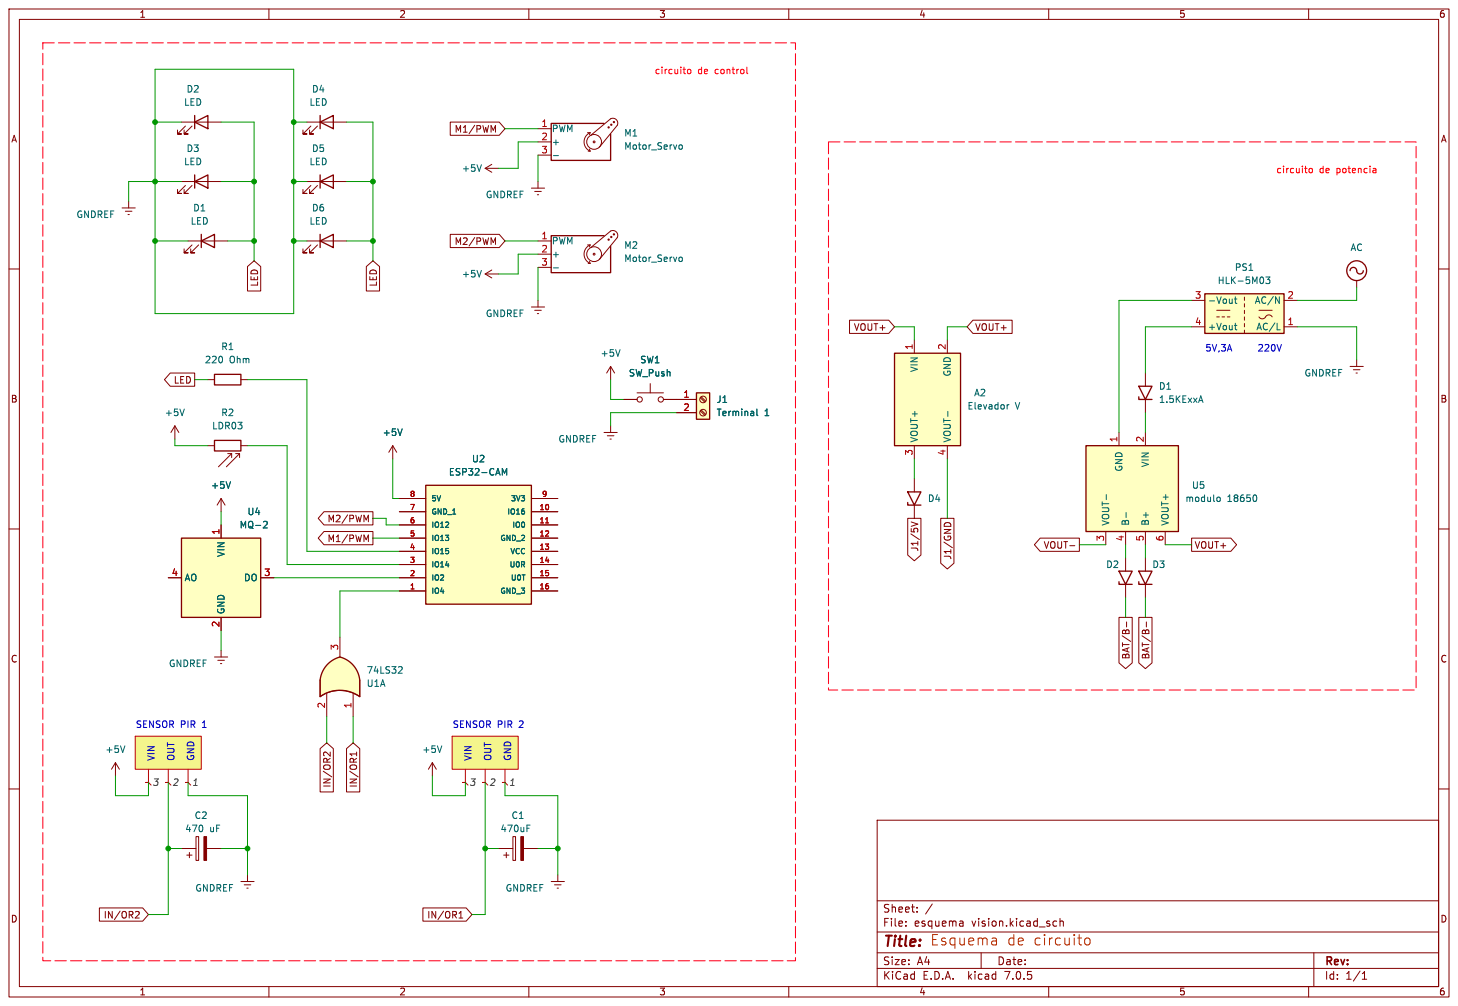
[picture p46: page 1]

Id: 1/1 Title: File: esquema vision.kicad_sch Sheet: /

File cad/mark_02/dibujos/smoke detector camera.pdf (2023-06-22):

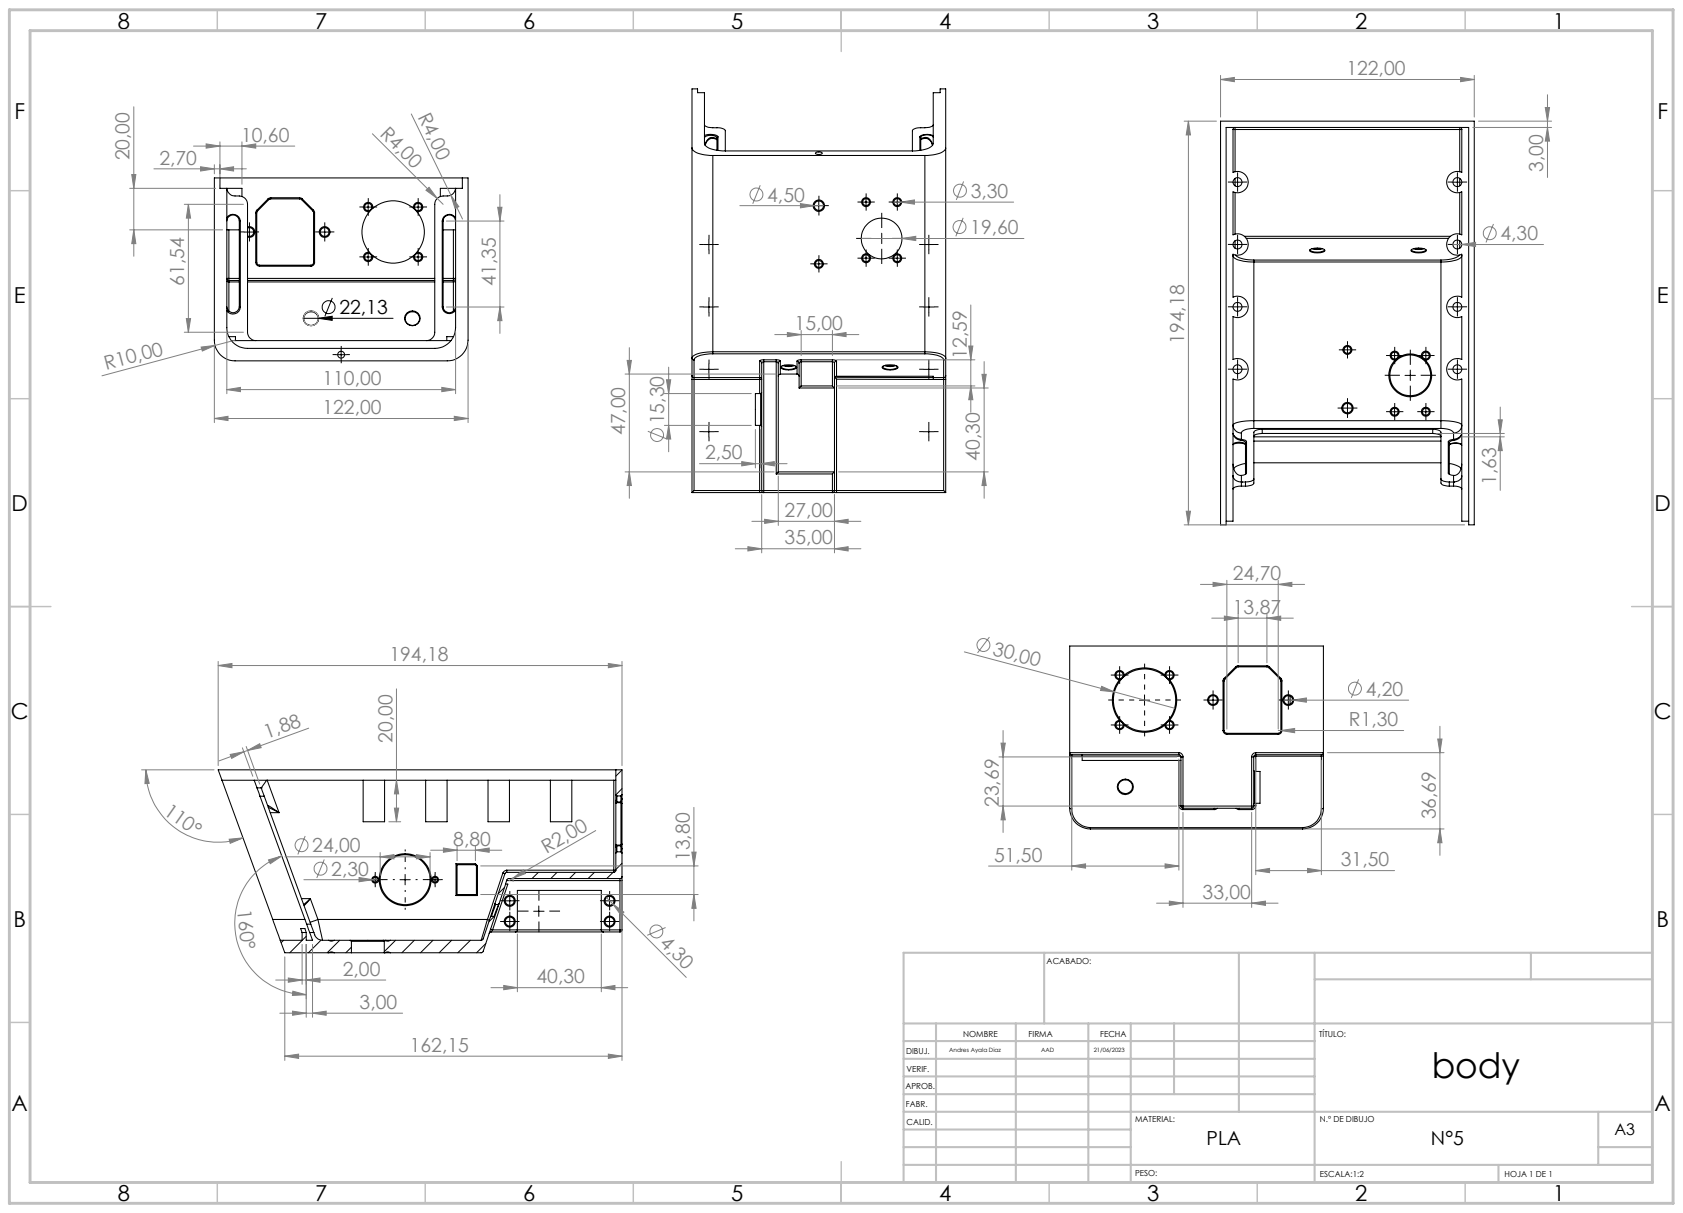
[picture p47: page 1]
ESCALA:1:2; HOJA 1 DE 1

ACABADO:

NOMBRE | FIRMA | FECHA | | | | TÍTULO:

DIBUJ. | | AAD | 21/06/2023 | | | | body Andres Ayala Diaz

VERIF.
APROB.
FABR.
CALID. | | | | MATERIAL: PLA | N.º DE DIBUJO N°5 | A3

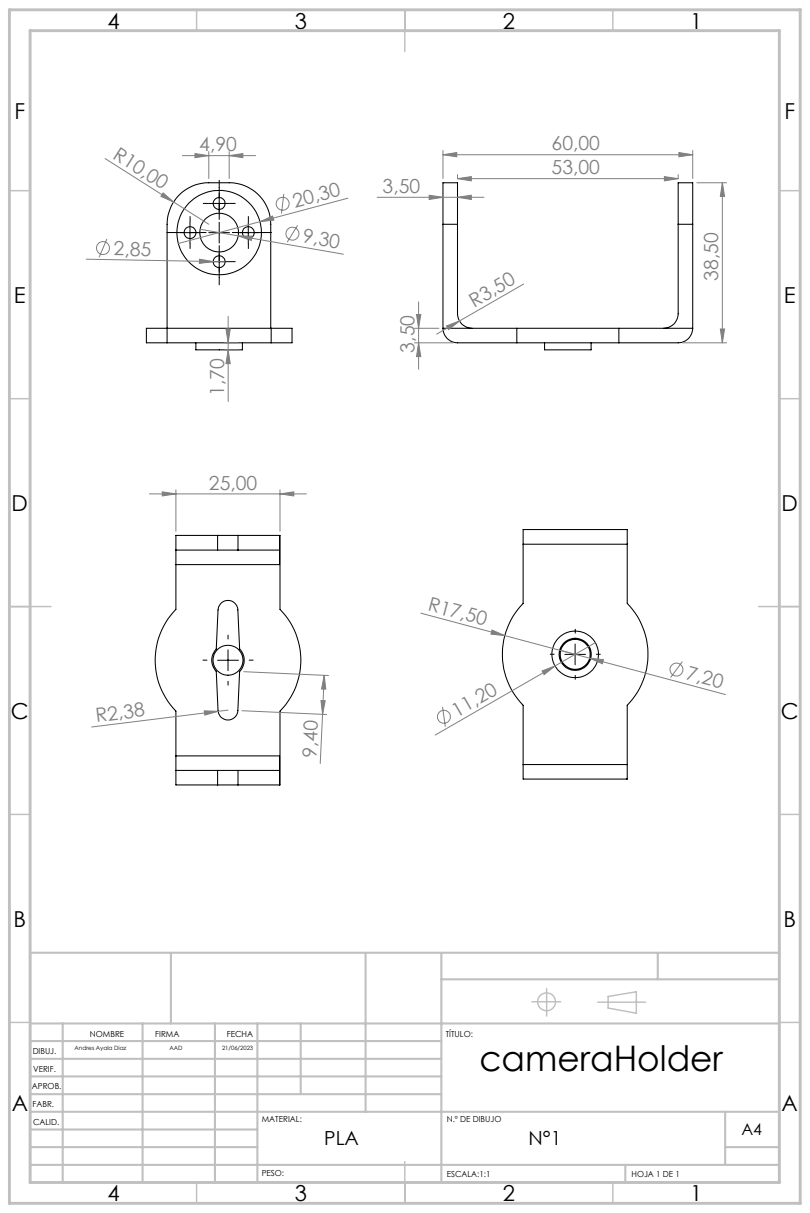
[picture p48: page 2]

NOMBRE | FIRMA | FECHA | | | | TÍTULO: cameraHolder

DIBUJ. | Andres Ayala Diaz | AAD | 21/06/2023
VERIF.
APROB.
FABR.

PLA | N°1

ESCALA:1:1 | HOJA 1 DE 1

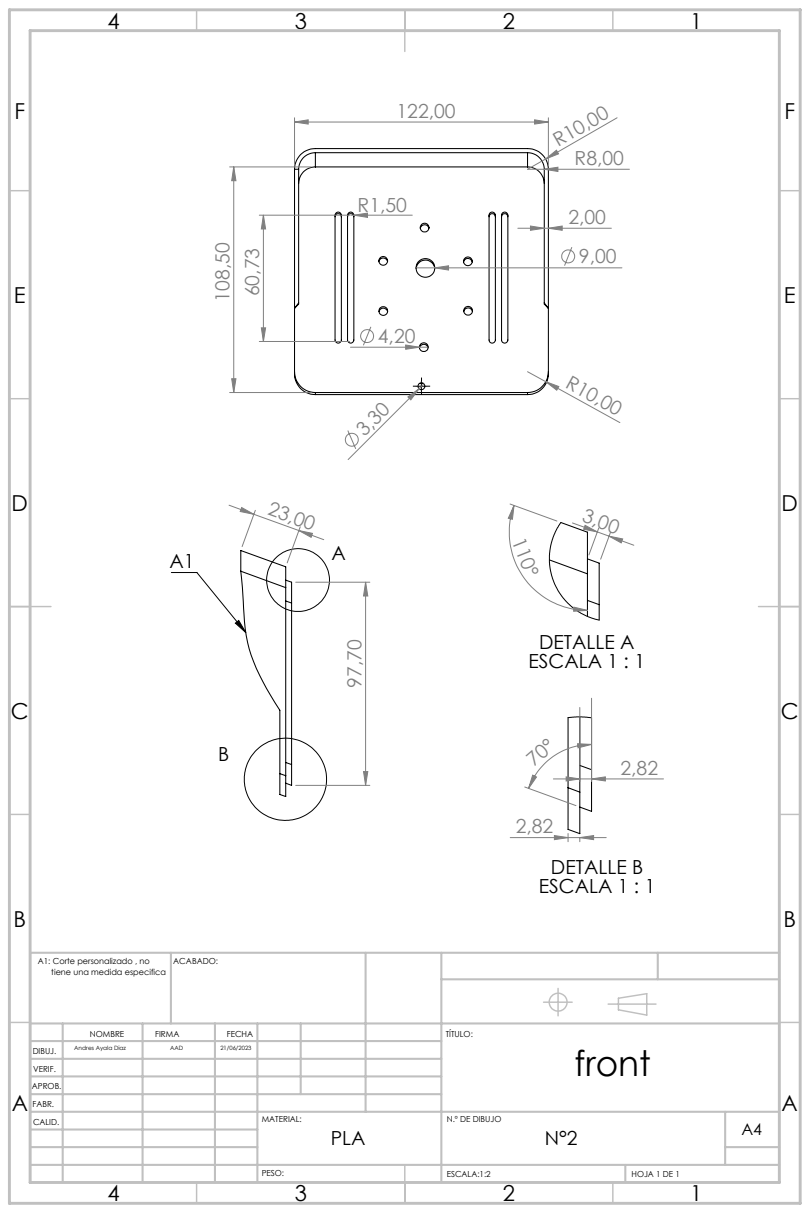
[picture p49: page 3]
DETALLE B ESCALA 1 : 1; DETALLE A ESCALA 1 : 1

A1: Corte personalizado , no tiene una medida especifica | ACABADO:

DIBUJ. | | AAD | 21/06/2023 | front Andres Ayala Diaz

NOMBRE | FIRMA | FECHA | TÍTULO:

VERIF.
APROB.
FABR.

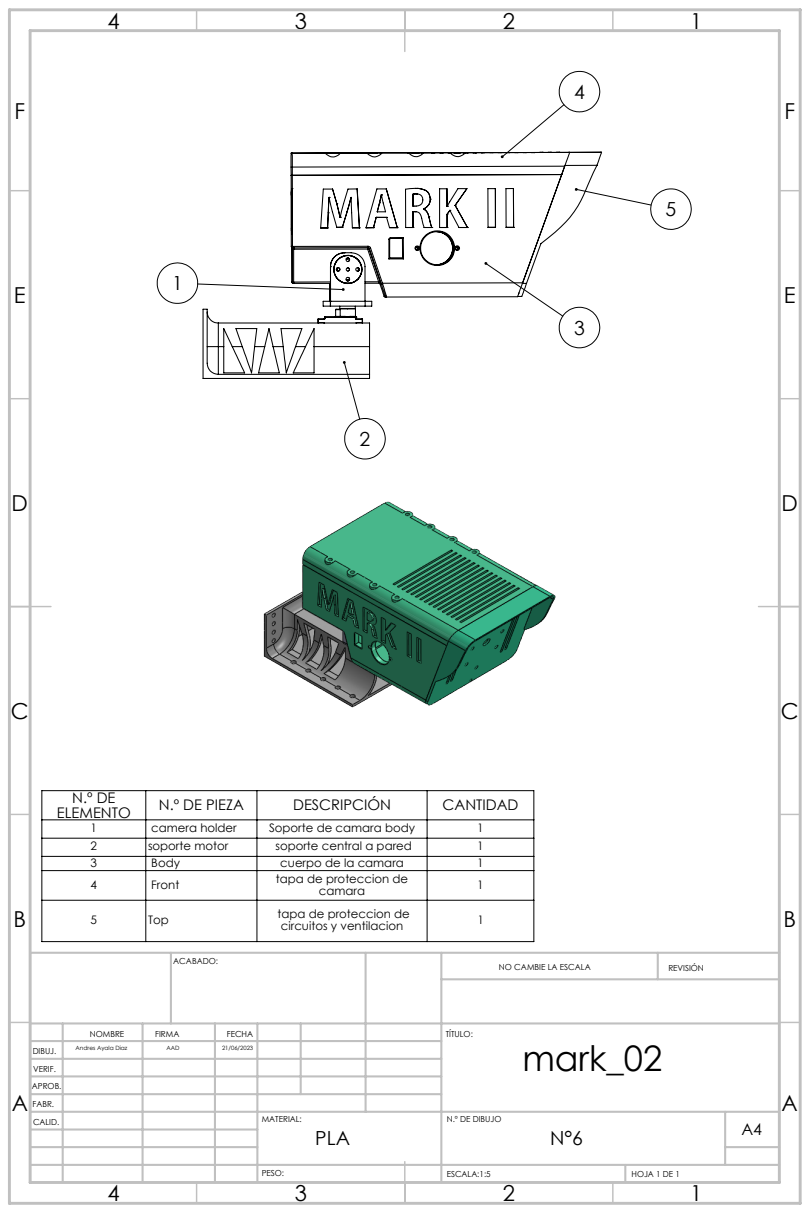
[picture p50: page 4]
NO CAMBIE LA ESCALA; REVISIÓN; ESCALA:1:5; HOJA 1 DE 1

N.º DE ELEMENTO | N.º DE PIEZA | DESCRIPCIÓN | CANTIDAD

1 | camera holder | Soporte de camara body | 1
2 | soporte motor | soporte central a pared | 1
3 | Body | cuerpo de la camara | 1
4 | Front | tapa de proteccion de camara | 1

5 | Top | tapa de proteccion de circuitos y ventilacion | 1

NOMBRE | FIRMA | FECHA | TÍTULO: mark_02

DIBUJ. | Andres Ayala Diaz | AAD | 21/06/2023
VERIF.
APROB.
FABR.

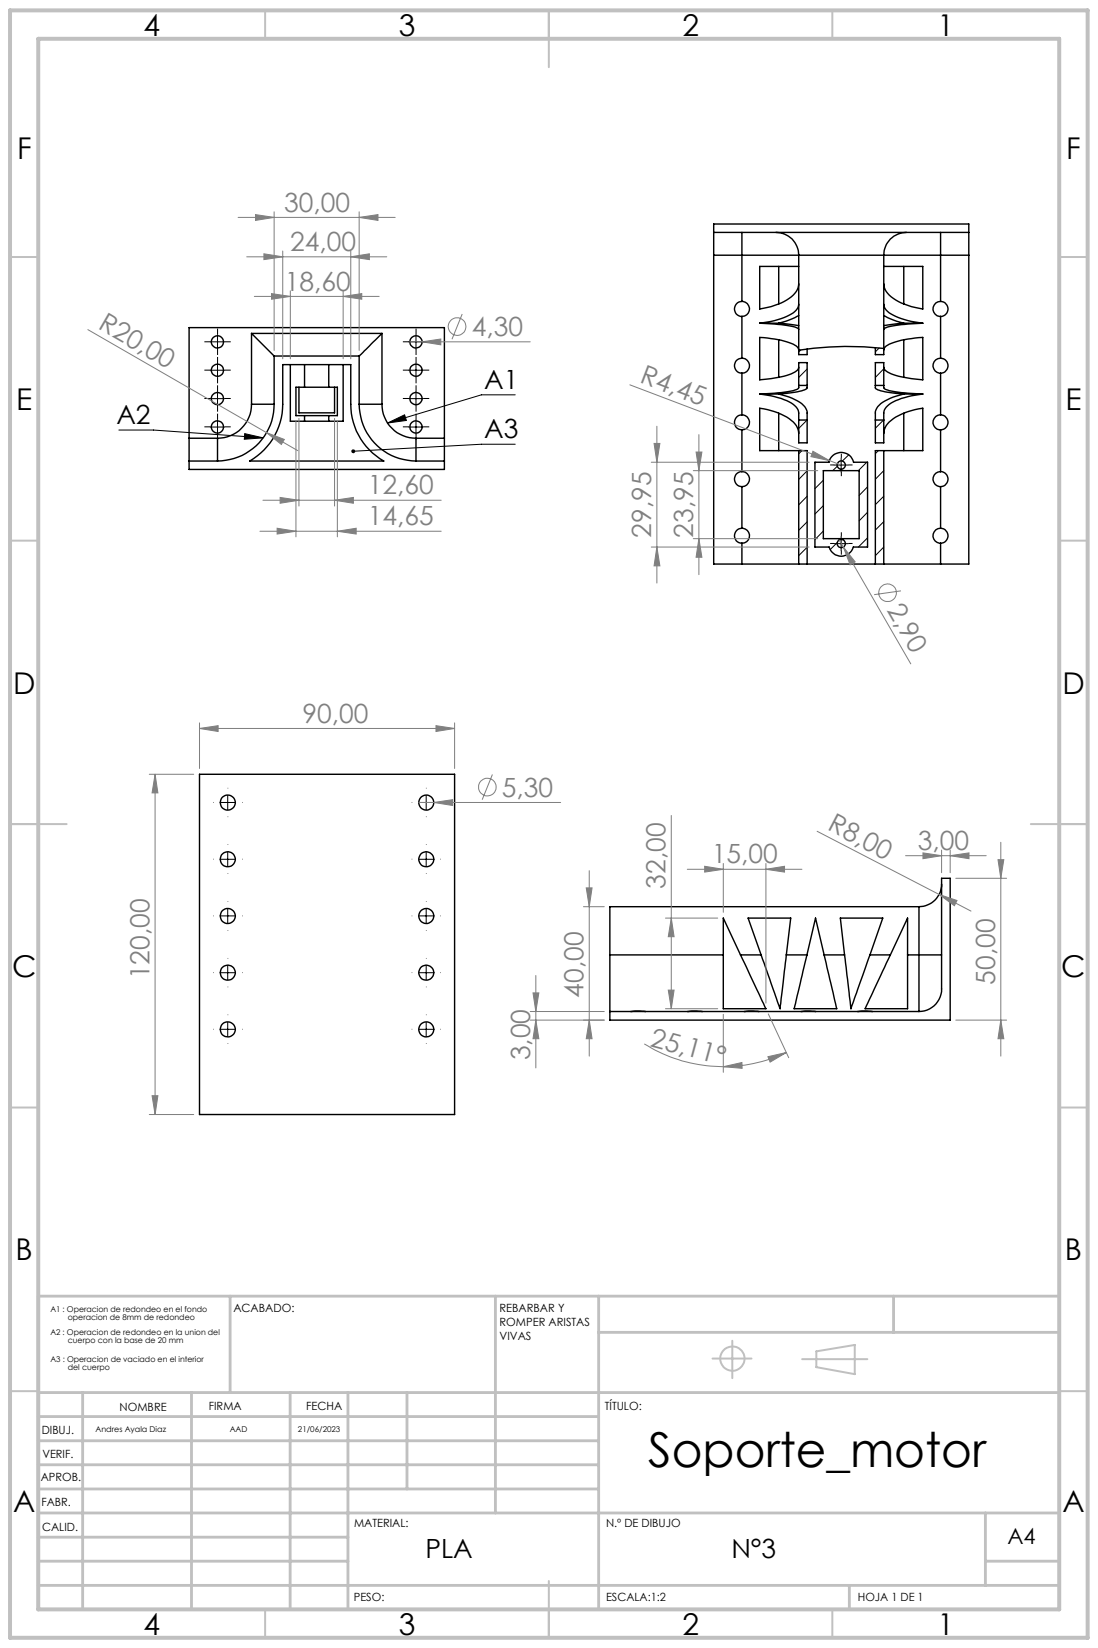
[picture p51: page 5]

A1 : Operacion de redondeo en el fondo operacion de 8mm de redondeo A2 : Operacion de redondeo en la union del cuerpo con la base de 20 mm A3 : Operacion de vaciado en el interior del cuerpo | ACABADO: | REBARBAR Y ROMPER ARISTAS VIVAS

NOMBRE | FIRMA | FECHA | TÍTULO: Soporte_motor

DIBUJ. | Andres Ayala Diaz | AAD | 21/06/2023
VERIF.
APROB.
FABR.

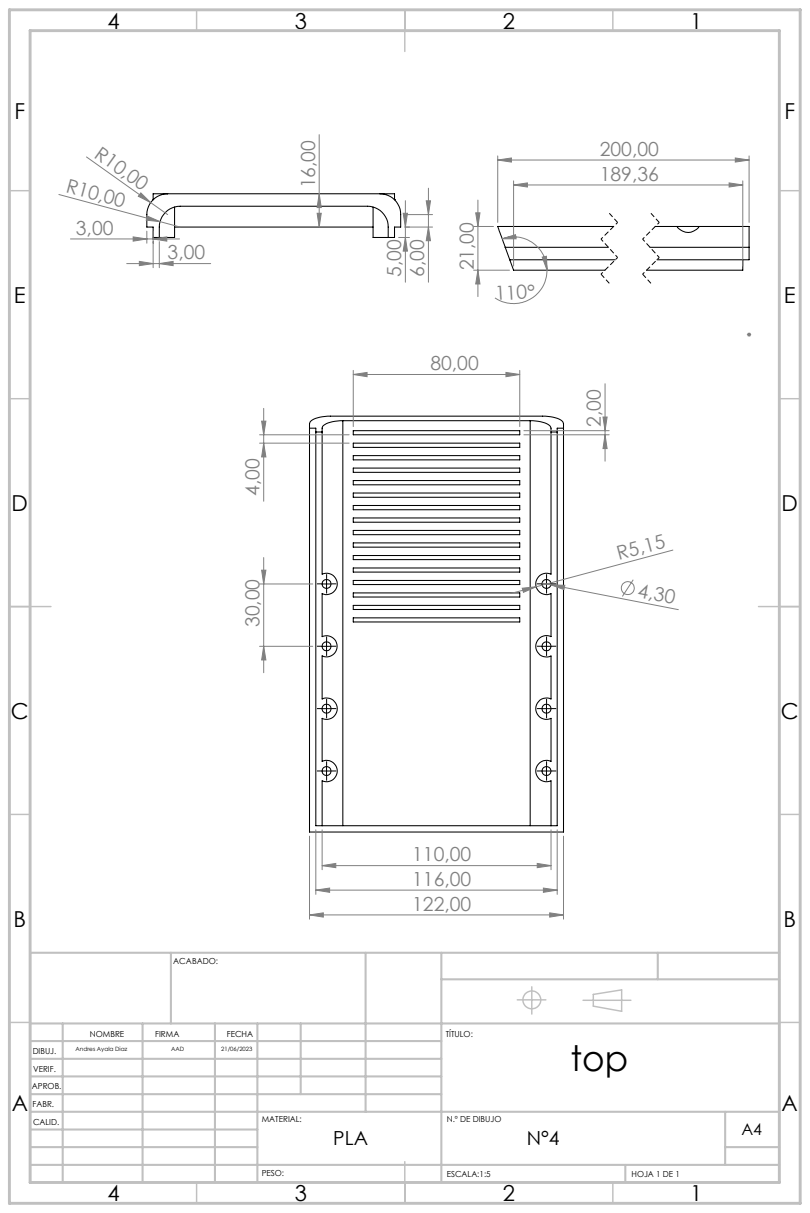
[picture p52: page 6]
ESCALA:1:5; HOJA 1 DE 1

ACABADO:

DIBUJ. | | AAD | 21/06/2023 | top Andres Ayala Diaz

NOMBRE | FIRMA | FECHA | TÍTULO:

VERIF.
APROB.
FABR.

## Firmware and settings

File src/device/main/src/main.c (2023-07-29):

/*******************************************************************************
 * @file        main.c
 * @author      Leonardo Acha Boiano
 * @date        27 May 2023
 * @brief       Main code of the Smoke Detector Camera Device
 * 
 * @note        This code is written in C and is used on an ESP32-CAM development board.
 *
 *******************************************************************************/

#include "main.h"

// Global variable to store the authenticated user's role
UserRole authenticatedUserRole;

// Entry point of the application
void app_main(void)
{
    esp_err_t ret = nvs_flash_init();
    // Initialize NVS (Non-Volatile Storage)
    nvs_flash_init_custom(ret);

    #if ENABLE_BT
    init_bluetooth(ret);
    // Set the custom log output function
    esp_log_set_vprintf(bt_log_output);
    #endif /* ENABLE_BT */
    
    #if ENABLE_BLE
    // Initialize Bluetooth Low Energy
    startBLE();
    snprintf(notification, 
            sizeof(notification), "Initial Notification");
    // Set the custom log output function
    esp_log_set_vprintf(ble_log_output);
    #endif /* ENABLE_BLE */

    // Initialize the camera
    ESP_ERROR_CHECK(init_camera());

    // Initialize GPIO pins
    init_gpio();

    //Init interrupt gpios
    init_isr();

    //Init motor structures
    initialize_motors();

    //Initialize FreeRTOS Tasks
    initialize_tasks();

    // Connect to WiFi
    connect_wifi();

    // Start the web server
    start_webserver();
}

esp_err_t nvs_flash_init_custom(esp_err_t ret){
    if (ret == ESP_ERR_NVS_NO_FREE_PAGES || ret == ESP_ERR_NVS_NEW_VERSION_FOUND)
    {
        ESP_ERROR_CHECK(nvs_flash_erase());
        ret = nvs_flash_init();
    }
    ESP_ERROR_CHECK(ret);

    return ESP_OK;
}

/********************************* END OF FILE ********************************/
/******************************************************************************/

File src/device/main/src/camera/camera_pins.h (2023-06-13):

#ifndef CAMERA_PINS_H_
#define CAMERA_PINS_H_

#define CONFIG_BOARD_ESP32CAM_AITHINKER 1

// Freenove ESP32-WROVER CAM Board PIN Map
#if CONFIG_BOARD_WROVER_KIT
#define CAM_PIN_PWDN -1  //power down is not used
#define CAM_PIN_RESET -1 //software reset will be performed
#define CAM_PIN_XCLK 21
#define CAM_PIN_SIOD 26
#define CAM_PIN_SIOC 27

#define CAM_PIN_D7 35
#define CAM_PIN_D6 34
#define CAM_PIN_D5 39
#define CAM_PIN_D4 36
#define CAM_PIN_D3 19
#define CAM_PIN_D2 18
#define CAM_PIN_D1 5
#define CAM_PIN_D0 4
#define CAM_PIN_VSYNC 25
#define CAM_PIN_HREF 23
#define CAM_PIN_PCLK 22
#endif

// ESP-EYE PIN Map
#if CONFIG_BOARD_CAMERA_MODEL_ESP_EYE
#define PWDN_GPIO_NUM    -1
#define RESET_GPIO_NUM   -1
#define XCLK_GPIO_NUM    4
#define SIOD_GPIO_NUM    18
#define SIOC_GPIO_NUM    23

#define Y9_GPIO_NUM      36
#define Y8_GPIO_NUM      37
#define Y7_GPIO_NUM      38
#define Y6_GPIO_NUM      39
#define Y5_GPIO_NUM      35
#define Y4_GPIO_NUM      14
#define Y3_GPIO_NUM      13
#define Y2_GPIO_NUM      34
#define VSYNC_GPIO_NUM   5
#define HREF_GPIO_NUM    27
#define PCLK_GPIO_NUM    25
#endif


// AiThinker ESP32Cam PIN Map
#if CONFIG_BOARD_ESP32CAM_AITHINKER
#define CAM_PIN_PWDN 32
#define CAM_PIN_RESET -1 //software reset will be performed
#define CAM_PIN_XCLK 0
#define CAM_PIN_SIOD 26
#define CAM_PIN_SIOC 27

#define CAM_PIN_D7 35
#define CAM_PIN_D6 34
#define CAM_PIN_D5 39
#define CAM_PIN_D4 36
#define CAM_PIN_D3 21
#define CAM_PIN_D2 19
#define CAM_PIN_D1 18
#define CAM_PIN_D0 5
#define CAM_PIN_VSYNC 25
#define CAM_PIN_HREF 23
#define CAM_PIN_PCLK 22

#define GPIO_SERVO_1 12
#define GPIO_SERVO_2 13
#define GPIO_LEDs 15
#define GPIO_LDR 14
#define GPIO_SMOKE_SENSOR 2
#define GPIO_PIR_SIGNAL 4
#endif



// TTGO T-Journal ESP32 Camera PIN Map
#if CONFIG_BOARD_CAMERA_MODEL_TTGO_T_JOURNAL
#define PWDN_GPIO_NUM      0
#define RESET_GPIO_NUM    15
#define XCLK_GPIO_NUM     27
#define SIOD_GPIO_NUM     25
#define SIOC_GPIO_NUM     23

#define Y9_GPIO_NUM       19
#define Y8_GPIO_NUM       36
#define Y7_GPIO_NUM       18
#define Y6_GPIO_NUM       39
#define Y5_GPIO_NUM        5
#define Y4_GPIO_NUM       34
#define Y3_GPIO_NUM       35
#define Y2_GPIO_NUM       17
#define VSYNC_GPIO_NUM    22
#define HREF_GPIO_NUM     26
#define PCLK_GPIO_NUM     21
#endif

#endif

/********************************* END OF FILE ********************************/
/******************************************************************************/

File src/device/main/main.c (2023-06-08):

/*******************************************************************************
 * @file        main.c
 * @author      Leonardo Acha Boiano
 * @date        27 May 2023
 * @brief       Main code of the Smoke Detector Camera Device
 * 
 * @note        This code is written in C and is used on an ESP32-CAM development board.
 *
 *******************************************************************************/

#include <esp_system.h>
#include <nvs_flash.h>
#include "freertos/FreeRTOS.h"
#include "freertos/task.h"
#include "driver/gpio.h"
#include "esp_timer.h"

#include "connect_wifi.h"
#include "camera_utils.h"
#include "web_server.c"
#include "http_handlers.h"

// Boundary for multipart/x-mixed-replace content type
#define PART_BOUNDARY "123456789000000000000987654321"
// Boundary for multipart/form-data content type
#define BOUNDARY "------------------------123456789000000000000987654321"

// Global variable to store the authenticated user's role
UserRole authenticatedUserRole;

// Entry point of the application
void app_main(void)
{
    // Initialize NVS (Non-Volatile Storage) to store WiFi configuration
    esp_err_t ret = nvs_flash_init();
    if (ret == ESP_ERR_NVS_NO_FREE_PAGES || ret == ESP_ERR_NVS_NEW_VERSION_FOUND)
    {
        ESP_ERROR_CHECK(nvs_flash_erase());
        ret = nvs_flash_init();
    }
    ESP_ERROR_CHECK(ret);

    // Connect to WiFi
    connect_wifi();

    // Initialize the camera
    ESP_ERROR_CHECK(init_camera());

    // Start the web server
    start_webserver();
}

/********************************* END OF FILE ********************************/
/******************************************************************************/

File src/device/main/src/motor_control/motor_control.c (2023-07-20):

/*******************************************************************************
 * @file        motor_control.c
 * @author      Leonardo Acha Boiano
 * @date        12 Jun 2023
 * 
 * @note        This code is written in C and is used on an ESP32-CAM development board.
 *              Based on servo driver from the ESP-IoT-Solution library.
 *
 *******************************************************************************/
#include "../motor_control/motor_control.h"

Motor create_motor(ledc_mode_t speed_mode, uint8_t channel) {
    Motor motor;
    motor.speed_mode = speed_mode;
    motor.channel = channel;
    motor.angle = 0.0f;
    motor.is_active = true;
    return motor;
}

//Global motor strucures
Motor motor1;
Motor motor2;

void initialize_motors()
{
    motor1 = create_motor(MOTOR_1_SPEED_MODE, MOTOR_1_CHANNEL);
    motor2 = create_motor(MOTOR_2_SPEED_MODE, MOTOR_2_CHANNEL);
}

void start_motor_movement(Motor *motor) {
    motor->is_active = true;
}

void stop_motor_movement(Motor *motor) {
    motor->is_active = false;
}

esp_err_t move_motor(const Motor *motor, float angle) {
    MOTOR_CHECK(motor->speed_mode < LEDC_SPEED_MODE_MAX, "LEDC speed mode invalid", ESP_ERR_INVALID_ARG);
    MOTOR_CHECK(motor->channel < LEDC_CHANNEL_MAX, "LEDC channel number too large", ESP_ERR_INVALID_ARG);
    MOTOR_CHECK(angle >= 0.0f, "Angle can't be negative", ESP_ERR_INVALID_ARG);

    esp_err_t result;
    uint32_t duty = calculate_duty(angle);
    result = ledc_set_duty(motor->speed_mode, (ledc_channel_t)motor->channel, duty);
    result |= ledc_update_duty(motor->speed_mode, (ledc_channel_t)motor->channel);

    MOTOR_CHECK(ESP_OK == result, "write servo angle failed", ESP_FAIL);

    //uint32_t current_duty = ledc_get_duty(motor->speed_mode, (ledc_channel_t)motor->channel);
    //ESP_LOGI(MOTOR_TAG, "Actual motor duty cycle for speed mode %d and channel %d: %lu Angle: %.2f Duty: %lu", motor->speed_mode, motor->channel, (unsigned long)current_duty, motor->angle, (unsigned long)duty);

    return ESP_OK;
}

uint32_t calculate_duty(float angle) {
    uint32_t duty  = (uint32_t)(SERVO_WIDTH_MIN_US + ((SERVO_WIDTH_MAX_US - SERVO_WIDTH_MIN_US) * angle) / SERVO_MAX_ANGLE);
    return duty;
}

// Motor getter
float get_motor_angle(const Motor *motor)
{
    return motor->angle;
}

// Motor setter
void set_motor_angle(Motor *motor, float angle)
{
    motor->angle = angle;
}

/********************************* END OF FILE ********************************/
/******************************************************************************/

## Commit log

2023-05-28 README update with cad and electronics dirs descriptions
2023-06-02 mark 00 cad files added
    [Base motor.SLDPRT, Ensamblaje1.SLDASM, Esamblaje camara.SLDASM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]
2023-06-05 added header documentation to the src/device files
2023-06-08 further modifications in folder structure indice the devices src dir to improve modularity
2023-06-09 added mark 01 cad updates
    [Base motor.SLDPRT, DC_FAN_30x30x6.stp, Esamblaje camara.SLDASM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]
2023-06-09 cad files updated untill mark01
    [Base motor.SLDPRT, DC_FAN_30x30x6.stp, Ensamblaje1.SLDASM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]
2023-06-09 Cambios en el index y statistics
2023-06-11 updated cad up to mark_02
    [Base motor.SLDPRT, CameraHolder.SLDASM, DC_FAN_30x30x6.SLDPRT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]
2023-06-13 servo motor piout constant change to match naming standart in project
2023-06-13 Redocumented motor_control.h for admin user permissions and consistent motor naming.
2023-06-13 Motor Task Shell implemented
2023-06-19 mark2 modified
    [CameraHolder.SLDASM, MG955 horn.SLDPRT, MG955 horn.STL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]
2023-06-20 esp32 api endpoints documented
2023-06-20 device code implemented with several task in parallel but timeout error while taking pictures
    [gpio_utils.c, task_utils.c, task_utils.h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]
2023-06-21 Add files via upload
    subo los dibujos de cada solido
    [Soporte_motor.SLDDRW, body.SLDDRW, cameraHolder.SLDDRW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]
2023-06-22 GPIO_PIR_SIGNAL macro changed from 16 to 4 in order to use interrupts
2023-06-22 task initalization commented, camera hits deadline
2023-06-22 gpio interruptions fixed, fixed conflicts with camera
    [gpio_interrupts.c, gpio_utils.c, logging_utils.c]
2023-06-22 interrupts initialization moved out of gpio init function
2023-06-22 TODOs added to keep track of the needed changes
2023-06-22 implemented motor behavior using functional approach
2023-06-23 motor handlers join, header indicates which motor
2023-06-23 found and fixed error wiith task, ledc library is not compatible
    [http_handlers.c, main.c, motor_control.c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]
2023-06-23 mark ii schematic diagram
2023-06-29 script to visualize motor angle in real time
2023-06-29 fixed motor behavior, software test passed, hardware test not done yet
    [gpio_utils.c, http_handlers.c, logging_utils.c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]
2023-07-20 motor related ESP_LOGI messages commented since functionality was already tested
2024-01-25 camera image updated
